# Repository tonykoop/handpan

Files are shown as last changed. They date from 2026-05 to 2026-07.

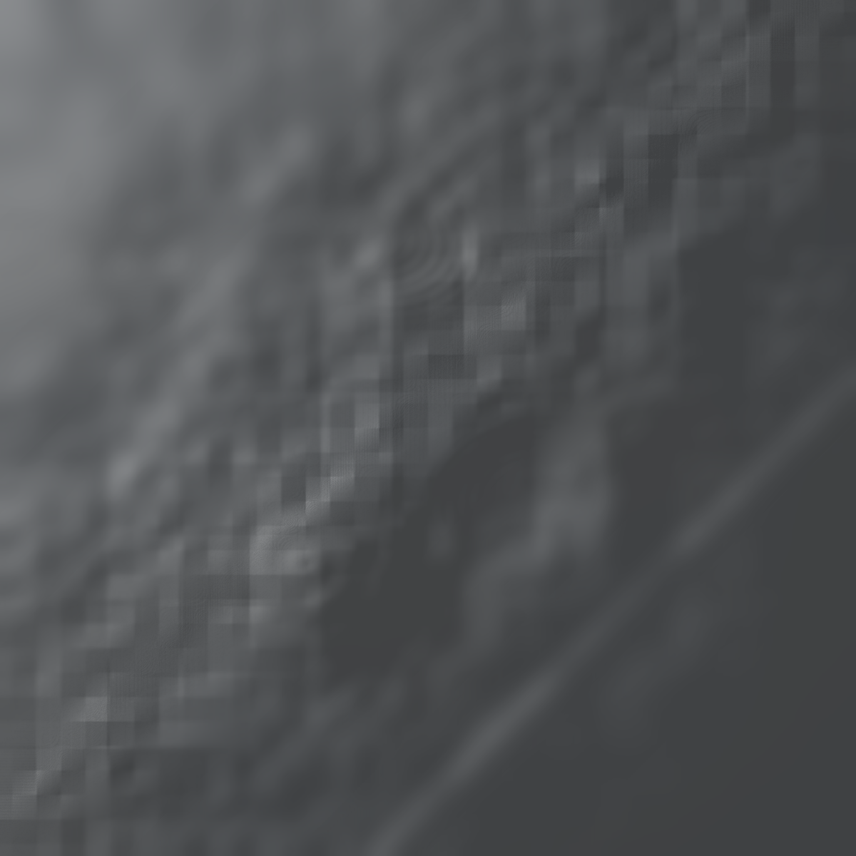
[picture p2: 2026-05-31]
images/macro/ding-and-tone-field.png

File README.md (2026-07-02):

# Handpan

Status: L2 V5 build-packet candidate; measurement-required before any L3/L4
tuning, CAD, or public-release claim.

Engineering documentation and parametric design table for a D Kurd root-mode handpan: the contemporary tuned-shell, tongueless metal hand drum built from two formed steel shells, a center Ding, eight surrounding tone fields, and a bottom Gu port.

Part of the [tonykoop/instrument-maker](https://github.com/tonykoop/instrument-maker) catalogue.

This repo is intentionally framed as a private research packet, not a promise that the spreadsheet can predict a finished handpan. Handpan tone fields are governed by hammered shell geometry, work-hardening, residual stress, shell coupling, heat/surface treatment, and tuner technique. The calculations in `handpan-design-table.xlsx`, `design.md`, and `handpan-starter.wl` are first-order sanity checks for scale, Gu behavior, and documentation. Final pitch, tuned dimple geometry, partial balance, sustain, and isolation must be earned through measured tuning passes on a real shell.

## Packet Map

- `design.md` - root-mode design intent, D Kurd note map, assumptions, and empirical tuning strategy.
- `tuning-tonality-notes.md` - Round 3 9-note D Kurd tonality notes, partial targets, and acoustic reference citations.
- `family-spec.csv` - root packet row plus variant rows that should not be released without measured prototypes.
- `bom.csv`, `sourcing.csv`, `cut-list.csv` - purchasing and fabrication surfaces with quote-sensitive fields kept explicit.
- `assembly-manual.md` - staged build method from shell inspection through settle/retune cycles.
- `validation.csv` - tuner-driven acceptance plan for cents error, partials, sustain, cross-talk, Gu coupling, and retuning drift.
- `validation-loop.csv` - Round 31 measurement loop for shell inspection, forming, heat/surface treatment, tuning, cross-talk, Gu response, and review gates.
- `measured-partial-strike-log.csv` - empty Round 35a strike/FFT/cross-talk log template; all rows remain `measurement_required` until real shell captures are recorded.
- `visual-output-register.csv` - authority map that keeps workbook/design-table inputs separate from concept-only SVG/PDF/explorer visuals.
- `cad/mcp-session-log.md` - provenance note recording that no MCP-generated V5 artifacts were produced in the Round 31 patch.
- `measurement-protocol.md` - issue #7 protocol for measured partials,
  cross-talk strike logs, microphone posture, and claim gates.
- `data/measured-partial-log.csv` - blank measurement template for field
  fundamentals and partial captures; no measured values are present yet.
- `data/cross-talk-strike-log.csv` - blank strike-log template for neighbor
  response and isolation review; no measured values are present yet.
- `qmd-step-0.md` - Round 2 retrieval record and QMD crash note.
- `validation-report.md` - current validator results and human-review gates before any public release.
- `public-release-checklist.md` - explicit path from private research packet to safe public release.
- `risks.md` - red-team review covering metal forming, heat/work-hardening, repeatability, and public-release limits.
- `drawing-brief.md`, `cad/handpan-cad-brief.md`, `cnc/fixture-cnc-brief.md`, `drawings/drawing-index.md` - CAD/CNC/drawing briefs for shells, fixtures, templates, and inspection views.
- `capstone-deck.md`, `capstone-manifest.json`, `print-packet.md`, `print-packet.html`, `site/index.html` - presentation, print, and static-site handoff artifacts.
- `cad/handpan.scad` - non-dimensional two-shell bounding envelope (top/bottom
  shell, rim joint, Ding-zone marker, Gu port); authority `pending_measurement`.
  Tone-field dimple geometry is explicitly out of scope.
- `evolution/` - evolution-pipeline Stage 0 intake: master manifest,
  design-intent, and revision register (Gate A not yet run).

## Current Root Mode

The current packet starts from the workbook defaults:

- Scale: D Kurd, 9 notes.
- Shell: 21 in nominal diameter, 9.5 in total height, 1.0 mm steel.
- Material path: nitrided DC04 preferred for first controlled build; stainless is allowed as a separate measured branch.
- Gu: 3.5 in nominal port with 0.5 in rolled lip, yielding a workbook first-order Helmholtz estimate near 115 Hz.
- Notes: D3 Ding plus A3, Bb3, C4, D4, E4, F4, G4, A4 fields.

## Round 31 V5 Issue Boundary

For the Round 31 V5 issue sweep, this repo is a private research/prototype
planning packet. It is useful for procurement, fixture planning, tuner review,
and evidence capture, but it is not L3, build-ready, measured, or publicly
release-ready evidence. The D Kurd note map and Gu estimate are documented
targets. Final pitch, dimple geometry, forming sequence, heat-treatment effects,
partial balance, sustain, cross-talk, and Gu response must be measured on a
real shell.

## Round 2 Issue #7 Measurement Surface

Issue #7 adds the missing measured-partial and cross-talk strike-log structure
before any stronger tuning claim. The note names in this repo remain target
program information only. The packet cannot claim tuned partials, field
isolation, final sustain, or public-ready musical behavior until
`data/measured-partial-log.csv` and `data/cross-talk-strike-log.csv` contain
real captures from a real shell, reviewed against `measurement-protocol.md`.

## Reality Check

The handpan should remain private until a human handpan tuner or metal-forming lead reviews the packet, approves the shell process, and signs off measured prototype data. The packet is useful for procurement, fixture planning, documentation, and validation discipline. It is not a guaranteed path to a concert instrument.

Issue #7 evidence starts in `measured-partial-strike-log.csv`. Do not promote tuning, partial-balance, sustain, or cross-talk claims from the D Kurd targets alone; each claim needs matching strike/FFT rows, audio or image evidence, and tuner review.

## Public Release Path

The repo is useful now as a private prototype handoff. Public release requires the gates in `public-release-checklist.md`: specialist review, supplier/process evidence, measured tuning data, safety review, and a public-claims pass. Until those are complete, describe the work as a research packet and fixture/documentation baseline.

## License

[CC BY 4.0](LICENSE) - see LICENSE for details.

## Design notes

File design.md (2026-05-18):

# Handpan Root-Mode Design

## Intent

Build a D Kurd handpan research packet that gives Tony's shop a practical first shell, tuning workflow, procurement list, validation plan, and documentation bundle while staying honest about the core unknown: handpan pitch is not determined by a single spreadsheet dimension. The root deliverable is a prototype-planning packet for a tuner-led build, not a guarantee of final musical quality or a measured V5 build packet.

## Design Position

- Instrument: handpan / hang-style steel idiophone.
- Mode: root-mode packet at repo root.
- Scale: D Kurd, Ding plus eight tone fields.
- Target use: first controlled prototype, tuning practice shell, documentation baseline.
- Existing source artifact: `handpan-design-table.xlsx`, sheet `Handpan`.
- Governing model: coupled curved steel plate fields plus Helmholtz Gu cavity.
- Model confidence: low for final pitch, medium for rough geometric scale and Gu sanity checks.

## Starting Inputs From Workbook

| Parameter | Value | Status |
|---|---:|---|
| Shell outside diameter | 21 in / 533 mm | workbook input |
| Total shell height | 9.5 in / 241 mm | workbook input |
| Steel thickness | 1.0 mm | workbook input |
| Gu port diameter | 3.5 in / 89 mm | workbook input |
| Gu lip / neck depth | 0.5 in / 13 mm | workbook input |
| Tuning standard | A4 = 440 Hz | workbook input |
| Number of tone fields | 9 | workbook input |
| Material | nitrided DC04 preferred | workbook input |

The workbook estimates Gu frequency from a Helmholtz expression using a lenticular volume approximation. With the current inputs, the Gu estimate is about 115 Hz, near Bb2, before real shell volume, port edge shape, and air/loading effects are measured.

## Target Scale

| Field | Note | MIDI | Fundamental Hz | Octave Hz | Compound 5th Hz | Layout | First field size estimate |
|---|---:|---:|---:|---:|---:|---|---|
| Ding | D3 | 50 | 146.83 | 293.66 | 440.00 | center | formed convex dome, tuner-defined |
| Field 1 | A3 | 57 | 220.00 | 440.00 | 660.00 | lower left | 3.50 x 4.55 in oval estimate |
| Field 2 | Bb3 | 58 | 233.08 | 466.16 | 699.23 | lower right | 3.40 x 4.42 in oval estimate |
| Field 3 | C4 | 60 | 261.63 | 523.25 | 784.88 | mid left | 3.21 x 4.17 in oval estimate |
| Field 4 | D4 | 62 | 293.66 | 587.33 | 880.00 | mid right | 3.03 x 3.94 in oval estimate |
| Field 5 | E4 | 64 | 329.63 | 659.26 | 988.88 | upper left | 2.86 x 3.72 in oval estimate |
| Field 6 | F4 | 65 | 349.23 | 698.46 | 1047.69 | upper right | 2.78 x 3.61 in oval estimate |
| Field 7 | G4 | 67 | 392.00 | 784.00 | 1176.00 | top left | 2.62 x 3.41 in oval estimate |
| Field 8 | A4 | 69 | 440.00 | 880.00 | 1320.00 | top right | 2.47 x 3.22 in oval estimate |

Field sizes are only layout starters. They should be used to make removable templates and inspection overlays, not final machining drawings.

## Acoustic Model

The first-order plate sanity check is:

```text
f1 ~= (kappa / (2 pi)) * (h / a^2) * sqrt(E / (rho * (1 - nu^2)))
```

where `h` is sheet thickness, `a` is an effective tone-field radius, and `E`, `rho`, and `nu` are steel properties. For a real handpan this equation is incomplete because hammered curvature, residual stress, work-hardening, anisotropic stiffness, dimple shape, shell boundary conditions, and coupling to other fields all shift the modes.

The Gu sanity check is:

```text
fH = (c / (2 pi)) * sqrt(A / (V * Leff))
```

where `A` is the Gu area, `V` is enclosed shell volume, and `Leff` is the port neck with end correction. The Gu should be measured after the shells are joined, because the actual cavity volume and port edge are build-specific.

## Empirical Tuning Strategy

The prototype is accepted by measurement, not prediction:

1. Form or purchase matched shells and document diameter, height, thickness map, mass, and material certificate.
2. Mark the Ding and eight fields using removable templates from the table above.
3. Rough-form the Ding and fields, leaving pitch intentionally flat enough to allow upward tuning.
4. Record baseline impulse response for every field before final tuning.
5. Tune the Ding first, then the lowest surrounding field upward through the scale.
6. For each field, tune three partial targets: fundamental, octave, and compound fifth.
7. After each field is adjusted, remeasure all previously tuned fields for drift and cross-talk.
8. Join shells only after the top shell is stable enough to survive a 24-hour rest without large drift.
9. After glue cure, tune through the Gu, then repeat rest and retune cycles until drift is acceptable.

## Acceptance Targets

- Fundamental cents error: goal within +/-8 cents after final settle, stretch target +/-5 cents.
- Octave partial: goal within +/-12 cents relative to 2x fundamental.
- Compound fifth partial: goal within +/-15 cents relative to 3x fundamental.
- Sustain: record T60 or practical decay-to-noise time per field; flag fields that choke or ring excessively.
- Cross-talk: striking any field should not pull a neighbor louder than -18 dB relative to the struck field's fundamental unless musically intentional.
- Retuning drift: after a one-week rest, each fundamental should remain within +/-10 cents of its last accepted measurement.

## Deliberate Unknowns

- Final field geometry after tuning is TBD until measured.
- Hammer recipes are TBD and must be logged by the tuner.
- Heat treatment schedule is supplier/process dependent.
- Dimple geometry, shoulder shape, and tone-field isolation are measurement-required and must not be inferred from the starter SVG layout.
- Adhesive selection needs compatibility testing with shell finish and rim geometry.
- Public release status is TBD until IP, safety, supplier, and human tuning review are complete.

## Build Classification

This is a root-mode research packet. It is suitable for a controlled first prototype, quote requests, fixture planning, shop review, and build-log setup. It is not suitable as a public "make a guaranteed handpan" recipe. See `validation-loop.csv` for the measurement gates that must close before any stronger readiness claim.

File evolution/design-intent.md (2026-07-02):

# Design Intent — handpan rev A

- Master CAD: `cad/handpan.scad` (sha256: 10a5e8d80ba57a5c706bd6ea92a2c84ce4aafa239d8eb2ffeb1638af2aa49fca) — a non-dimensional two-shell bounding envelope, driven by `handpan-design-table.xlsx` (sha256: 80c50005ce95baa1bfa12314e45540738dd1dd5cb3201e6eb3768304953d73db).
- Function: D Kurd root-mode handpan / hang-style steel idiophone. Two hammered steel shells form a Ding (center) plus eight surrounding tone fields and a bottom Gu (Helmholtz) port, coupled through the shell body (design.md Design Position, Governing Model). Tone field pitch is earned by measured tuning passes, not predicted by geometry (design.md Empirical Tuning Strategy).
- Environment: struck/hand-played idiophone; thin steel shells are forming-hazard-sensitive (risks.md Metal Forming Hazards).
- Target qty: 1 (prototype). Deadline: TBD. Budget/unit ceiling: TBD.

## Critical dimensions (carry tolerances)

| Feature | Nominal | Tolerance | Why critical | Source |
| --- | --- | --- | --- | --- |
| Shell outside diameter | 21 in / 533 mm | workbook input, not measured | overall envelope, fixture sizing | design.md Starting Inputs From Workbook, cad/handpan-cad-brief.md |
| Total shell height | 9.5 in / 241 mm | workbook input, not measured | envelope, rim-joint planning | design.md Starting Inputs From Workbook |
| Steel thickness | 1.0 mm | workbook input, not measured | pitch model input, forming risk | design.md Starting Inputs From Workbook |
| Gu port diameter / neck depth | 3.5 in / 0.5 in | workbook input, not measured | Helmholtz sanity check only | design.md Starting Inputs From Workbook |
| Tone field layout (9 fields incl. Ding) | design.md Target Scale table (layout starters only) | measurement_required — explicitly OUT OF SCOPE for cad/handpan.scad | final pitch, tuner-driven | design.md Target Scale; cad/handpan-cad-brief.md "Do not model tuned tone fields as final manufacturable pitch geometry" |

## Incidental (free for DFM)

- Shell surface finish/color; ding-zone marker diameter in cad/handpan.scad (layout reference only, not a tuned dimple spec).

## Must-nots (DFM may never violate)

- Never model tone-field dimple geometry as final manufacturable pitch geometry — cad/handpan.scad is envelope-only per cad/handpan-cad-brief.md.
- Do not treat handpan-design-table.xlsx scale values as calibrated tuned geometry (register DST-001: authority pending_measurement).
- Do not join shells before the top shell survives a 24-hour rest without large drift (design.md Empirical Tuning Strategy step 8).
- Follow risks.md Metal Forming Hazards PPE/fixture mitigations before any forming or hammering pass.

## Material intent

- Preferred: nitrided DC04 steel shells (design.md Starting Inputs From Workbook); see bom.csv/sourcing.csv for procurement detail.
- Acceptable subs: per risks.md Heat And Work-Hardening Assumptions — do not mix stainless and nitrided assumptions in one measurement set.
- Forbidden: none recorded.

## Stage status

Stage 0 intake complete 2026-07-01. Gate A (Alpha shop compile) NOT yet run — no concessions logged, nothing presented as shippable.

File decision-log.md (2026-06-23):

# Handpan Decision Log

## Decision 1 — Shell Material and Tuner Path

**Status:** Decided (planning-level; no measurement evidence yet)
**Refs:** issue #7

### Shell

| Option | Chosen? | Rationale |
|---|:--:|---|
| DC04 deep-draw steel, 2.0 mm blank | **Yes** | Widely available from Metall Pfeiffer/Havel or domestic steel service; known forming behavior; case-hardening via nitriding is available as an optional post-form step |
| Stainless 304 / 316, 1.5 mm blank | Fallback | Higher spring-back; tooling force increase; research path only |
| Nitrided / hardened pre-treated sheet | Deferred | Pre-nitrided stock is scarce; defer until DC04 path is validated |

**Chosen path:** Start with DC04 raw blank. Shell thickness target: 2.0 mm flat, ~1.2 mm measured at formed crown after hydroforming or deep press. Nitriding is an optional post-form step, not a prerequisite.

### Tuner / FFT Capture

| Option | Chosen? | Rationale |
|---|:--:|---|
| Peterson StroboPlus HD (hardware strobe) | **Yes** | Reference-grade ±0.1 cent accuracy; offline; no cloud dependency |
| Audacity FFT (software, laptop mic) | Yes (supplemental) | Free; cross-check only; mic placement and room must be logged |
| Android tuner app (GStrings, etc.) | No (initial) | Insufficient accuracy for compound-fifth partial verification |

**Chosen path:** Primary capture = Peterson StroboPlus HD + close-field mic (~5 cm, cardioid) into Audacity for FFT screenshot. Every row in `measured-partial-strike-log.csv` must name the tuner model, gain setting, room noise level, and audio file or FFT screenshot path.

### Public / Private Handling for Evidence

| Artifact | Public? | Rationale |
|---|:--:|---|
| Protocol template (`measurement-protocol.md`) | Public | Process definition only; no shell-specific data |
| Log template (`measured-partial-strike-log.csv`, `data/measured-partial-log.csv`) | Public | Template rows marked `measurement_required`; no real values |
| Populated log rows (real Hz readings, FFT screenshots) | **Private until reviewed** | Measurement evidence is retained locally in `data/`; only a reviewed summary is committed to main |
| Audio captures (`.wav`, `.flac`) | Private / local only | Large files; store locally or in private object storage; never commit to GitHub |

**Decision:** Only template rows and protocol docs are committed public. Populated measurement rows go into `data/` (already listed in `.gitignore` drafts) until a tuning lead or fabrication reviewer signs off. After review, a sanitized summary row is promoted to `measured-partial-strike-log.csv` with a reference to the private evidence file path.

## Packet Readiness Gate

The packet stays at **L2 planning** (templates defined, protocol decided, no real shell evidence) until at least:

- [ ] One physical shell blank acquired and logged in `validation-loop.csv` vl001
- [ ] Material/process path documented with supplier cert or process note (vl002)
- [ ] Template layout photographed and reviewed (vl003)
- [ ] Ding fundamental and octave partial captured and within ±5 cents of target (vl004)

Advancing to L3 requires real measured rows, not template rows.

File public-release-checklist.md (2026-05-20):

# Public Release Checklist

This repo can be useful before it is publicly releasable. Treat the current packet as a private research and shop-review bundle until every gate below is complete.

## Current Use

Allowed now:

- Quote shells, tooling, measurement equipment, fixtures, adhesive coupons, and finishing supplies.
- Review the D Kurd layout, Gu target, and validation method.
- Build non-acoustic fixtures: tuning support ring, removable templates, inspection overlays, and photo/documentation setup.
- Run scrap-shell or coupon trials for hammers, edge finishing, adhesive, and finish compatibility.

Not allowed to claim yet:

- Final tone-field contours.
- A proven hammer recipe or tuning sequence.
- Concert-quality pitch accuracy, sustain, or cross-talk isolation.
- Validated nitriding, heat-treatment, stainless, or supplier process behavior.
- A general public recipe for building a finished handpan.

## Specialist Gates

| Gate | Required reviewer | Evidence to add |
|---|---|---|
| Shell process | Experienced handpan maker or metal-forming lead | Supplier shell data, material certificate, forming notes, thickness map, mass, hardness/process notes if available |
| Tone-field forming | Experienced handpan tuner | Signed review of layout, hammer plan, stop conditions, and tuning-log fields |
| Heat / surface process | Heat-treatment or supplier reviewer | Nitriding/stainless branch decision, process temperature notes, distortion risk, compatibility with finish and adhesive |
| Safety | Shop lead | PPE plan, hearing protection plan, Gu/rim deburr inspection, fixture stability, fire/fume plan if heat is used |
| Public release | Tony plus IP/public-safety reviewer | Confirmation that photos, supplier details, methods, claims, and terminology are safe to publish |

## Measurement Gates

Populate `validation.csv` before public release:

- Incoming shell diameter, height, thickness map, mass, material path, and Gu geometry.
- Gu response after assembly or controlled cavity test.
- Ding plus eight field fundamentals, backed by `measured-partial-strike-log.csv`.
- Octave and compound fifth partials for every field, backed by FFT/strobe rows in `measured-partial-strike-log.csv`.
- Strike matrix for cross-talk, with struck-field and neighbor-field rows in `measured-partial-strike-log.csv`.
- Sustain or practical decay for every field, linked to the same strike-log evidence.
- Post-assembly drift after at least one week.
- Final Gu/rim tactile safety inspection.

## Drawing Gates

The current drawings are layout and inspection drawings. Before public release, add or revise:

- General assembly view from actual shell measurements.
- Bottom Gu drawing from the final cut port and edge treatment.
- Measurement overlay for shell-thickness points, strike locations, and microphone reference.
- Template sheet labeled `layout estimate`, not `final tone geometry`.
- Photos or screenshots showing the real prototype, not only schematic layouts.

## Release Decision

The issue can be considered complete for a private build packet when the repo validates cleanly and clearly escalates the human-only work.

The repo should not be called public-ready until the specialist and measurement gates above are complete.

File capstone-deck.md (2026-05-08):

# Title

D Kurd Handpan Root-Mode Prototype

# Project Intent

Create a research-grade root packet for a D Kurd handpan that is useful in the shop and honest about uncertainty. The packet supports shell procurement, fixture planning, layout, empirical tuning, validation, and private review before any public release.

# Instrument Context

The handpan is a coupled steel-shell idiophone with a center Ding, surrounding tuned fields, and a bottom Gu port. Its musical behavior comes from shaped steel, residual stress, tuned partials, and shell coupling.

# Source Artifacts

The starting design comes from `handpan-design-table.xlsx`, sheet `Handpan`, with a 21 in shell, 1.0 mm steel, 3.5 in Gu, A=440, and a D Kurd 9-note layout.

# Physics Model

The packet uses plate and Helmholtz formulas as first-order sanity checks only. Final pitch is determined by measured hammered geometry, work-hardening, boundary conditions, field coupling, and tuner decisions.

# Scale And Layout

The target root mode is D Kurd: D3 Ding with A3, Bb3, C4, D4, E4, F4, G4, and A4 surrounding fields. The oval field sizes are removable-template starters, not final acoustic contours.

# Manufacturing Strategy

The first build should use purchased or professionally formed shells. CNC and CAD are used for support rings, templates, drawings, and inspection aids rather than final tuned tone-field geometry.

# Tuning Workflow

Tune the Ding first, then move from low fields to high fields. Each field is measured for fundamental, octave, and compound fifth, and each change triggers a recheck of previously tuned fields.

# Validation Plan

Acceptance is tuner-driven: cents error, overtone behavior, sustain, cross-talk, Gu response, and retuning drift are logged across rough tuning, shell closure, final tuning, and one-week rest cycles.

# Risks

Major risks include metal-forming hazards, heat-treatment distortion, tuning repeatability, false precision in formulas, adhesive/rim effects, and premature public release. These are documented in `risks.md`.

# Private Review Gate

The handpan should stay private until a human tuner and metal-forming reviewer approve the process and measured data. The packet is a disciplined prototype handoff, not a finished-instrument guarantee.

# Deliverables

The repo now includes design, BOM, sourcing, cut list, validation, assembly, RFQ, drawing/CAD/CNC briefs, visual BOM brief, Wolfram starter, risks, photo shotlist, print packet, site, and capstone manifest artifacts.

# Next Actions

Source or inspect a practice shell, verify supplier data, build the tuning frame and templates, run coupon tests, and begin a measured tuning log before committing the final shell pair.

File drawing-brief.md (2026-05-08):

# Drawing Brief

## Purpose

Create drawings that help a fabricator, tuner, and reviewer inspect the handpan prototype. These drawings should not imply that the tone fields can be machined to final pitch. They are layout, fixture, inspection, and communication drawings.

## Required Drawing Set

1. General assembly side view: two-shell lenticular body, 21 in nominal diameter, 9.5 in total height, rim joint, bottom Gu location.
2. Top layout view: Ding and eight field clock positions, note names, target fundamentals, and estimated oval layout envelopes.
3. Bottom view: Gu center, 3.5 in nominal port, lip/edge finish note.
4. Section view: shell thickness, rim bond region, Gu lip, and approximate internal volume region.
5. Fixture view: tuning support ring contact surface and shell support datum.
6. Template sheet: Ding and eight removable layout templates.
7. Validation overlay: measurement point map for thickness, strike positions, and microphone reference.

## Drawing Rules

- Mark all tone-field final shapes as `tuner adjusted`.
- Mark field dimensions as `layout estimates`.
- Include both inch and metric dimensions.
- Include datum references: shell center, 12 o'clock reference, rim plane, Gu center.
- Avoid CNC-style final contour dimensions for tuned areas.
- Add notes for inspection and measurement logging.

## CAD/CNC Deliverables

- `cad/handpan-cad-brief.md` for model setup.
- `cnc/fixture-cnc-brief.md` for support ring and templates.
- `drawings/drawing-index.md` for drawing list and review gates.

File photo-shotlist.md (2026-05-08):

# Photo Shotlist

## Incoming Materials

- Shell pair top, side, inside, rim, and bottom views.
- Closeups of material markings, supplier labels, and surface finish.
- Thickness measurement setup and measurement grid.
- Gu port before and after deburring.

## Layout And Forming

- Centerline and clock reference on top shell.
- Ding template aligned to shell center.
- Each tone-field template in place with note label visible.
- Tuning frame/support ring before shell is placed.
- Dimple tooling and hammer set with scale reference.

## Tuning Documentation

- Microphone/tuner setup showing fixed distance.
- FFT/spectrum screen for each field's three partials.
- Tuning log page after one complete pass.
- Cross-talk measurement setup.
- Rest/retune comparison table.

## Assembly

- Dry-fit rim alignment marks.
- Adhesive coupon test.
- Adhesive bead before shell closure.
- Clamping setup during cure.
- Gu access during final tuning.

## Finish And Final Review

- Finished Gu edge.
- Surface protection application.
- Final assembled top, side, and bottom views.
- Case/storage setup.
- Human tuner review session or marked measurement signoff.

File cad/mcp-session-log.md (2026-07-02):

# MCP Session Log

No MCP-generated V5 artifacts were produced for this Round 31 patch.

The current handpan packet contains text-authored docs, CSVs, workbook-derived
planning values, starter SVG drawings, and an existing studio explorer. These
are useful for review and prototype planning, but they are not evidence of a
measured handpan, calibrated tuned dimple geometry, verified forming process,
heat-treatment recipe, or final shop-ready tone-field layout.

| timestamp_utc | tool | artifact | session_id | parent_artifact | role | authority | notes |
| --- | --- | --- | --- | --- | --- | --- | --- |
| 2026-05-18 | none | visual-output-register.csv | none | handpan-design-table.xlsx | authority register | metadata | Records workbook/design-table authority and concept-only visual previews. |
| 2026-05-18 | none | validation-loop.csv | none | validation.csv | validation loop | measurement plan | Adds measurement-required gates for shell inspection, forming, tuning, Gu response, cross-talk, and human review. |
| 2026-05-29 | none | visual-output-register.csv rows SVG-003, DXF-001 | none | DST-001 | dimple layout pre-registration | pending | Registered planned Illustrator MCP dimple-layout vector artifacts (issue #4). Session not yet run; authority=pending. Files do not yet exist. Upgrade authority to fabrication after running MCP session and validating DXF dimensions against design-table. |
| 2026-05-29 | none | validation.csv rows VAL-023, VAL-024, VAL-025 | none | measured-partial-strike-log.csv | validation gates | measurement plan | Added strike-log completeness gate (VAL-023), cross-talk matrix completeness gate (VAL-024), and dimple layout fabrication pre-gate (VAL-025) — issue #7 and #4 protocol structure. |
| 2026-07-01 | claude-code (Fable 5) | bom.csv, sourcing.csv, cut-list.csv, validation.csv, handpan-design-table.xlsx, family-spec.csv | fable-v5-refresh-2026-07-01 | handpan-design-table.xlsx | packet_refresh | fabrication | V5 refresh pass: reviewed tabular packet data against design-table baseline; no dimension changes made. Row added to satisfy V5 fabrication-artifact logging requirement. |
| 2026-07-01 | claude-code (Fable 5) + OpenSCAD CLI | cad/handpan.scad | fable-v5-refresh-2026-07-01 | handpan-design-table.xlsx, design.md, cad/handpan-cad-brief.md | cad_authoring | pending_measurement | Non-dimensional two-shell bounding envelope (top/bottom shell, rim joint, Ding-zone marker, Gu port) authored from workbook-input scale dimensions (shell_diameter_in=21, shell_height_in=9.5, steel_thickness_mm=1.0, gu_diameter_in=3.5). Tone-field dimple geometry explicitly out of scope per cad/handpan-cad-brief.md ("Do not model tuned tone fields as final manufacturable pitch geometry"). OpenSCAD render check: pass (openscad -o STL, exit 0). |

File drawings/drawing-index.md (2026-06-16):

# Drawing Index

## Planned Drawings

| Drawing | Purpose | Status |
|---|---|---|
| HPAN-001 Top Layout | Ding and eight field clock positions with target notes | `01-top-layout.svg` |
| HPAN-002 Section / Fixture | Shell side profile, rim joint, Gu port, total height, tuning support ring | `02-gu-section-fixture.svg` |
| HPAN-003 General Assembly | Overall 21 in shell pair, rim, Gu, top/bottom orientation | brief ready |
| HPAN-004 Bottom Gu | Gu port diameter, edge/lip note, safety finish | brief ready |
| HPAN-005 Tuning Frame | Support ring geometry and contact notes | covered in HPAN-002 starter |
| HPAN-006 Template Sheet | Ding and tone-field layout templates | brief ready |
| HPAN-007 Validation Map | Strike points, mic placement, thickness map locations | brief ready |
| HPAN-008 Issue #4 Dimple Layout Vector Test | Illustrator-MCP register row and pending-authority brief for a future vector test | `issue-4-dimple-layout-vector-test.md` |

## Drawing Warning

All tone-field contours are layout estimates. Final shape and pitch are tuner-adjusted after measured hammering passes.

The starter SVGs are intentionally conservative review drawings. They are suitable for layout discussion, fixture planning, and shop review; they are not final manufacturable tone-field geometry.

Issue #4 does not add a new vector drawing. Its brief records the gates a future
Illustrator-MCP dimple-layout test must satisfy before any vector output can be
treated as more than `pending_measurement`.

## Public-Release Drawing Gates

Before public release, replace or supplement the starter drawings with actual shell measurements and build evidence:

- actual shell profile, rim condition, and Gu edge detail
- measurement overlay for shell thickness, strike points, and microphone placement
- template sheet labeled as `layout estimate`
- photo references for the real shell and fixtures
- reviewer signoff that no drawing implies CNC-machined final pitch geometry

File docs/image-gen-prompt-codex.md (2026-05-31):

# Image-Gen Prompts

Concept image only; not fabrication authority. Do not include cut-ready dimensions, tone-field templates, dimple geometry, tuning values, shell process parameters, or toolpaths.

## Hero Prompt

Photorealistic 3/4 product photograph of a finished D Kurd research handpan: two joined nitrided steel shells forming a smooth lenticular hand drum, a central Ding dome surrounded by eight tuned oval tone fields, subtle hammered and heat-treated surface texture, a rolled rim seam, bottom Gu port hinted by the side shadow, dark blue-gray satin steel with gentle iridescence, realistic lap-playable scale cues, clean neutral studio background, soft directional studio lighting, ~50mm lens, high detail, no logos.

## In-Context Prompt

Photorealistic workshop tuning scene of the handpan on a padded stand, natural light over the nitrided shell, a tuner gently strikes a tone field while removable paper templates, small hammers, and a measurement microphone sit nearby, the Ding and surrounding D Kurd fields visible as formed surfaces rather than cut tongues, quiet private research atmosphere, realistic hands, shallow depth of field, concept visualization only.

## Detail Prompt

Photorealistic macro close-up of the signature handpan tone-field surface: one oval formed field with a central dimple and shoulder transition in dark nitrided steel, fine hammer marks, subtle heat-treatment color, neighboring fields and the Ding softly blurred, a fingertip or soft mallet just out of contact, soft raking light emphasizing curvature, high detail, no pitch labels or dimension overlays.

## Negative / Avoid

No text, logos, watermarks, slit tongues, ceramic surface, dimension callouts, fake brand emblems, impossible perfectly flat tone fields, extra fingers, or decorative patterns unrelated to the D Kurd handpan layout.

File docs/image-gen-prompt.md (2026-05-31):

# Image-Gen Prompts

Concept image only; not fabrication authority. Do not include cut-ready dimensions, hole locations, tone-field geometry, dimple shapes, or toolpaths. Tone-field shapes are tuner-adjusted and must never be drawn as final.

## Hero Prompt

Photorealistic 3/4 product photograph of a finished D Kurd handpan: a smooth lenticular UFO-shaped steel hand drum formed from two domed sheet-steel shells joined at a clean rim seam, a single convex central Ding dome at the top center surrounded by a ring of eight gently hammered oval tone fields, each tone field a softly dimpled depression with a subtle raised note interface, the whole satin-grey nitrided steel surface showing faint hammer-worked texture and a warm dark patina, hand-playable lap-scale cues, brushed metal catching soft directional studio light, clean neutral studio background, soft directional studio light, 3/4 angle, ~50mm lens, high detail, photorealistic, no text labels.

## In-Context Prompt

Photorealistic image of the D Kurd handpan staged on a player's lap in a quiet instrument-maker's workshop, the musician's hands resting lightly over the central Ding and an adjacent tone field as if about to strike, the lenticular steel body angled so the ring of eight oval tone fields around the Ding is visible, a tuning frame support ring and a small set of tuning hammers resting on the bench nearby for storytelling, warm natural window light, satin nitrided steel surface with faint hammer texture, shallow depth of field, environmental storytelling, concept visualization only.

## Detail Prompt

Photorealistic macro close-up of the signature mechanism: the central convex Ding dome and two neighboring hammered oval tone fields on the steel handpan top shell, each tone field a smooth shallow dimpled depression worked into the curved steel with soft shoulder transitions and subtle concentric hammer-forming marks, satin nitrided grey-steel surface with faint patina, raking light revealing the gentle curvature and worked texture of the shell, the rim seam blurred at the frame edge, high detail, no measurements.

## Negative / Avoid

No text, logos, watermarks, or fake maker marks; no dimension callouts; no cut tongues, slots, or machined tone-field contours (tongueless tuned-shell drum, tuner-adjusted fields); anatomically plausible hands if a player is shown.

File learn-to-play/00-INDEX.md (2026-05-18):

# Handpan — Starter Songbook

Your handpan is tuned to **D Kurd** (D natural minor / Aeolian):

```
Ding: D3 (center, lower dome)
Tone fields (arranged in a circle on the upper dome):
  A3 — Bb3 — C4 — D4 — E4 — F4 — G4 — A4
```

The handpan is played with bare hands — thumbs, fingertips, and the heel of the hand.
Never use mallets, picks, or hard objects on the handpan.

## Difficulty key
- ★☆☆ — Beginner: ding + adjacent fields, slow patterns
- ★★☆ — Intermediate: full field circle, simple melodies
- ★★★ — Advanced: bass tones, taks, cross-handed patterns

## Stroke vocabulary
| Stroke | Hand | Sound |
|---|---|---|
| **Ding** | Thumb or ring finger on ding dome | Deep, resonant center tone |
| **Tone** | Fingertip on outer edge of tone field | Clear, singing pitch |
| **Slap** | Flat finger, quick release | Short, muted "tak" click |
| **Bass** | Hand presses center of tone field then lifts | Muffled, bass-register version of field |

## Tunes in this songbook
1. `tunes/ding-meditation/` ★☆☆ — Ding exploration and drone patterns
2. `tunes/sakura/` ★★☆ — Sakura Sakura, Japanese trad. (A Bb D E)
3. `tunes/greensleeves-kurd/` ★★☆ — Greensleeves adapted for D Kurd
4. `tunes/kurd-dawn/` ★★★ — Kurd Dawn (original, D Aeolian)
5. `tunes/water-is-wide/` ★★★ — The Water Is Wide (D natural minor)

## Safety note
The handpan surface is finished steel. Keep fingernails trimmed. Do not use rings
or jewelry while playing. After playing, wipe the surface with a dry cloth and
apply a small amount of protective oil (phoenix oil or similar) monthly.

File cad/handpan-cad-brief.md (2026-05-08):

# CAD Brief - Handpan Prototype

## Scope

Model the handpan as an inspection and communication assembly: top shell, bottom shell, rim joint, Gu port, Ding zone, and eight layout zones. Do not model tuned tone fields as final manufacturable pitch geometry.

## Model Requirements

- Units: inches primary, metric secondary.
- Global variables: shell_diameter_in = 21, shell_height_in = 9.5, steel_thickness_mm = 1.0, gu_diameter_in = 3.5.
- Datums: rim plane, shell center axis, 12 o'clock clock reference, Gu center.
- Configurations: top shell layout, bottom shell Gu, assembled shell, exploded review view.
- Tone fields: surface decals/sketch envelopes only, named by note and target frequency.
- Properties table: material path, source shell, measured thickness map reference, mass.

## Review Notes

CAD is not the acoustic authority for final handpan pitch. Its job is to keep the shop aligned on shell geometry, tooling interfaces, templates, and validation points.

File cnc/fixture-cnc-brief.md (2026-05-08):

# CNC Brief - Fixtures And Templates

## Parts

1. Tuning support ring for 21 in shell.
2. Removable Ding template.
3. Eight oval tone-field layout templates.
4. Measurement overlay with strike and microphone reference marks.

## Materials

- Support ring: steel, plywood, or MDF prototype; final frame should be stiff and padded.
- Templates: acrylic, hardboard, plywood, or printed film.

## Constraints

- CNC parts support layout and measurement only.
- Do not cut, stamp, or machine final tone fields based solely on the CSV dimensions.
- Edges contacting the shell must be padded or polished.
- Mark all templates with note name, target Hz, and `layout estimate`.

## Output Files To Generate Later

- DXF/SVG support ring profile.
- DXF/SVG template sheet.
- PDF inspection overlay.

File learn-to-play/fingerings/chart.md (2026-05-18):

# Handpan Field Layout Reference (D Kurd)

```
         ┌──────────────────────────────┐
         │         TOP VIEW             │
         │                              │
         │       A4 ●     ● G4         │  ← 6 o'clock / 12 o'clock positions
         │                              │
         │   F4 ●             ● E4     │  ← 4:30 / 7:30 positions
         │                              │
         │       D4 ●     ● C4         │  ← 3 o'clock / 9 o'clock positions
         │                              │
         │   Bb3●              ● A3    │  ← 1:30 / 10:30 positions
         │                              │
         │         ╭─────────╮          │
         │         │ DING    │          │  ← Center dome (D3)
         │         │  D3     │          │
         │         ╰─────────╯          │
         └──────────────────────────────┘

Note: Actual clock positions vary by builder. This is a representative D Kurd layout.
Learn your specific instrument's field positions by touch before reading notation.
```

## Stroke techniques
| Stroke | Finger | Sound |
|---|---|---|
| Ding | Thumb or ring fingertip | Deep, resonant, long sustain |
| Tone | Fingertip (index or middle) at field center | Clear singing tone |
| Tak/slap | Flat of finger, quick release | Short percussive click |
| Bass slap | Whole hand, muffle after strike | Low, muted field tone |

## Field-to-note map (D Kurd, clockwise from lower left)
A3 → Bb3 → C4 → D4 → E4 → F4 → G4 → A4 (→ back to A3)

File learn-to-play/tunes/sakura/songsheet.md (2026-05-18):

# Sakura Sakura — Songsheet (Handpan)

**Key:** A Bb D E (Sakura/In pentatonic)  **Tempo:** ♩= 66
**Meter:** 4/4  **Difficulty:** ★★☆  **Range:** A3–E4
**Source:** Traditional Japanese, Edo period, public domain

## Music
```
X:2 T:Sakura Sakura M:4/4 L:1/4 Q:1/4=66 K:Dmin
A B d2 | A B d2 | A B d e | d B A2 |
A B d e | d B A2 | A d d B | A4 |
```

## Handpan fingering notes
- **A3** (A): left or right index finger on the A3 field (first field from ding)
- **Bb3** (B): adjacent field
- **D4** (d): opposite side of the field circle
- **E4** (e): next field clockwise from D4
- Return to **A4** for the final held note (or use A3 + ding together)

## Notes
- At ♩= 66, this melody should feel like a slow koto improvisation.
- The Bb (b in K:Dmin) creates the distinctive Sakura/In scale tension.
- Let each note fully bloom before the next — the handpan sustain is your friend.

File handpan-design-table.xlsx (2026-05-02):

Handpan / Hang Drum — Clamped Steel Plate + Helmholtz Resonator
Steel Idiophone · Nitrided or Stainless Steel · Ding + 8 Tone Fields · Gu Port (Helmholtz Bass) · Hand-Tuned Harmonics
DESIGN INPUTS
Shell Diameter (in) | 21.0 | ← 53 cm standard; original Hang = 52 cm (20.5"); range 18–24"
Shell Height (in) | 9.5 | ← 8–10" typical; deeper = more bass resonance
Steel Thickness (mm) | 1.0 | ← 0.8–1.2 mm; thinner = easier to shape, higher pitch tendency
Gu Port Diameter (in) | 3.5 | ← 3–4.5"; larger = lower Helmholtz bass
Gu Port Depth (in) | 0.5 | ← Rolled lip depth (neck length for Helmholtz calc)
Material | Nitrided DC04 | ← DC04 (nitrided) | 430 Stainless | Ember Steel
Tuning Standard (Hz) | 440 | ← 440 Hz standard; some makers use 432 Hz
Number of Tone Fields | 9 | ← Ding (center) + 8 surrounding; range 7–17
Selected Scale | D Kurd | ← Choose from Scale Library below (row 30+)
GU BASS — Helmholtz Resonator: f = (c/2π)√(A / (V × L))
Speed of Sound (in/s) |  | ← At 68°F / 20°C
Gu Port Area (in²) |  | ← A = π × (port_Ø/2)²
Shell Internal Volume (in³) |  | ← V ≈ ⁴⁄₃πr²h (lenticular shell: 2 oblate spheroid halves)
Gu Neck Length (in) |  | ← Physical depth + end correction (0.6 × radius)
Helmholtz Frequency (Hz)
Nearest Note |  | ← Typical handpan Gu bass range: C2–G2
Cents Deviation |  | ← + sharp / − flat from nearest ET note
SCALE LIBRARY — Popular Handpan Tunings (Ding + 8 Tone Fields)
Scale Name | Mood | Ding | 1 | 2 | 3 | 4 | 5 | 6 | 7 | 8
D Kurd | Versatile minor | D3 | A3 | Bb3 | C4 | D4 | E4 | F4 | G4 | A4
D Celtic Minor | Open, spacious | D3 | A3 | C4 | D4 | E4 | F4 | G4 | A4 | C5
C# Pygmy | Dreamy, grounding | C#3 | G#3 | B3 | C#4 | D#4 | G#4 | B4 | C#5 | D#5
E Hijaz | Exotic, Middle Eastern | E3 | B3 | C4 | D#4 | E4 | F4 | G#4 | A4 | B4
D Equinox | Meditative, floating | D3 | A3 | C4 | D4 | E4 | G4 | A4 | C5 | D5
F Sabye | Happy, uplifting | F3 | C4 | D4 | F4 | G4 | A4 | C5 | D5 | F5
E Akebono | Zen, contemplative | E3 | B3 | C4 | E4 | F4 | B4 | C5 | E5 | F5
D Aeolian | Full natural minor | D3 | A3 | Bb3 | C4 | D4 | E4 | F4 | G4 | A4
← Copy your chosen scale’s notes to the Tone Field Calculator below
TONE FIELD CALCULATOR — 9-Note Layout (Ding + 8 Fields)
Field | Note Name | MIDI # | Fundamental (Hz) | Octave (Hz) | Compound 5th (Hz) | Position | Clock Pos | Est. Field Width (in) | Est. Field Height (in) | Status
Ding (center) | D3 | 50 |  |  |  | Center | — | — | — | Dome (convex)
Field 1 (lowest) | A3 | 57 |  |  |  | Bottom-Left | 7:00:00 |  |  | Dimple (concave)
Field 2 | Bb3 | 58 |  |  |  | Bottom-Right | 5:00:00 |  |  | Dimple (concave)
Field 3 | C4 | 60 |  |  |  | Mid-Left | 9:00:00 |  |  | Dimple (concave)
Field 4 | D4 | 62 |  |  |  | Mid-Right | 3:00:00 |  |  | Dimple (concave)
Field 5 | E4 | 64 |  |  |  | Upper-Left | 10:00:00 |  |  | Dimple (concave)
Field 6 | F4 | 65 |  |  |  | Upper-Right | 2:00:00 |  |  | Dimple (concave)
Field 7 | G4 | 67 |  |  |  | Top-Left | 11:00:00 |  |  | Dimple (concave)
Field 8 (highest) | A4 | 69 |  |  |  | Top-Right | 1:00:00 |  |  | Dimple (concave)
SHELL FORMING METHODS
Method | Description | Equipment | Pros | Cons | Feasibility
Hand Sinking | Hammer flat disc into concave form over sandbag/tire | Ball peen hammer, sandbag, pneumatic hammer | Lowest cost; most traditional | Very slow; inconsistent thickness | ✅ Home shop
Spinning | Clamp disc on lathe, press forming tool as disc spins | Metal lathe 22"+ swing, buck tool | More uniform; repeatable | Needs large lathe | ⚠️ Lathe too small
Deep Drawing | Hydraulic press pushes disc through die in one stroke | Hydraulic press + die, OR buy pre-drawn shells | Most consistent; buy shells $150-300/pair | Die set expensive | ✅ Buy shells (recommended)
Hydroforming | Water pressure pushes disc through mold | Hydroform press, mold | Excellent uniformity | Industrial only | ❌ Not feasible
STEEL & NITRIDING
Raw Material | DC04 low-carbon steel (most common) or 430/301 stainless steel
Sheet Thickness | 0.8-1.2 mm (1.0 mm standard)
Flat Disc Diameter | ~24 in (shell diam x 1.15 for draw overshoot)
Gas Nitriding | 500-550C in nitrogen atmosphere; hardens surface, ceramic tap tone | Outsource to nitriding facility
Nitriding Effect | Vickers ~1000 HV; tuning stability; darker color; rust resistance
BILL OF MATERIALS
# | Item | Qty | Spec / Dimensions | Supplier / Notes | Est. Cost
1 | Pre-drawn steel shells (pair) | 1 | 53cm / 21 in diam, 1.0mm DC04 or stainless | Ayasa Instruments, Shellopan, or similar supplier | $150-300
2 | Gas nitriding service | 1 | 500-550C nitrogen heat treatment (both shells) | Local nitriding facility; skip if using stainless | $50-150
3 | Tuning ring / clamping frame | 1 | Steel ring to hold shell during tuning | CNC cut from 1/4 in steel plate, or weld from flat bar | $30-80
4 | Tuning hammers (set) | 1 | Small cross-peen, ball peen, rubber mallet | Modified jeweler's hammers; 4-8 oz heads | $40-80
5 | Dimple press / ball form | 1 | Hardened steel ball + receiver die for dimple pressing | Can use arbor press with ball bearing; or hammer by hand | $20-50
6 | Chromatic tuner + spectrum analyzer | 1 | Peterson StroboClip or software (SpectraPLUS, Audacity FFT) | Need to see fundamental + overtones separately | $30-100
7 | Shell adhesive (epoxy) | 1 | High-strength, flexible epoxy (3M DP420 or similar) | Must remain slightly flexible; rigid epoxy cracks | $20-40
8 | Gu port ring (rubber) | 1 | 3.5 in ID rubber O-ring or silicone edge trim | Protects Gu edge; improves Helmholtz tone | $5-15
9 | Protective oil / sealant | 1 | Phoenix Oil, Frog Lube, or food-grade mineral oil | Apply after each playing session (nitrided only) | $10-20
10 | Padded case / bag | 1 | 22 in soft case or hard shell case | Essential for transport and storage | $40-100
 | ESTIMATED TOTAL |  |  |  | $395-935
BUILD METHOD
# | Phase | Operation | Tools | Key Parameters | Done?
1 | Shell Prep | Acquire or form two hemisphere shells | Supplier / hydraulic press | Match top + bottom shells; verify diameter and depth
2 | Shell Prep | Cut Gu port hole in bottom shell | Hole saw, deburr tool | 3.5 in diameter; center carefully; roll edge inward
3 | Nitriding | Send both shells to nitriding facility | Outsource | 500-550C gas nitriding; skip if stainless steel
4 | Layout | Mark Ding center and 8 tone field positions on top shell | Template, marker, compass | Zigzag L-R layout ascending; use clock positions from table above
5 | Layout | Mark tone field oval boundaries with templates | Oval templates (laser-cut acrylic) | Use estimated field sizes from calculator; larger fields at bottom
6 | Forming | Press or hammer dimples into each tone field center | Dimple press / ball form / hammer | Concave dimples for fields; convex dome for Ding
7 | Pre-Stress | Pre-stress tone fields by hammering around perimeters | Cross-peen hammer | Compress metal around each note to isolate vibrations
8 | Heat Treat | Heat shell with torch to relieve forming stresses | Propane/MAP torch | Heat until blue-purple (300-350C); let cool naturally
9 | Tuning | Tune Ding fundamental first | Tuning hammer, chromatic tuner | Center of Ding raises pitch; surrounding area lowers it
10 | Tuning | Tune each tone field fundamental (1 of 3 per field) | Tuning hammer, spectrum analyzer | Work from lowest (Field 1) to highest (Field 8)
11 | Tuning | Tune octave harmonic on each field (2 of 3) | Tuning hammer, FFT analyzer | Shape the field into two perpendicular axes (Pringle shape)
12 | Tuning | Tune compound 5th harmonic on each field (3 of 3) | Tuning hammer, FFT analyzer | Verify all 3 partials in tune; check isolation from neighbors
13 | Assembly | Glue top and bottom shells together | Flexible epoxy, clamps, alignment jig | Apply even bead around rim; clamp firmly; cure 24+ hours
14 | Fine Tune | Let settle 1-2 weeks, then re-tune through Gu port | Tuning hammer (reach through Gu) | Steel has memory; re-check all 27 partials (9 fields x 3)
15 | Fine Tune | Repeat settle + retune cycle 2-3 more times | Same | Each cycle: wait 1-2 weeks, retune. Tuning becomes more stable
16 | Finishing | Clean, polish, apply protective oil; install Gu ring | Microfiber cloth, oil, rubber ring | Remove glue residue; oil nitrided surface; trim Gu edge
DESIGN NOTES
1. TUNING IS THE HARDEST PART. Expect months of practice before producing a playable instrument. Start with a practice shell.
2. Each tone field has 3 tuned partials: fundamental, octave (+12 semitones), compound 5th (+19 semitones). All 3 must be in tune.
3. Tone field shape: think two Pringles stacked perpendicular. The two axes of the oval each vibrate at different frequencies.
4. Center of field raises pitch; hammering edges lowers pitch. Work incrementally — over-hammering is very hard to undo.
5. Wave interference: certain frequencies resonate with the shell cavity and create buzzing. The Helmholtz Gu frequency is key — avoid tuning any field to that frequency.
6. Pre-drawn shells from Ayasa or similar are STRONGLY recommended for first build. Hand-sinking requires enormous practice.
7. Nitriding is optional if using stainless steel. Stainless has longer sustain, warmer tone, no rust; nitrided has crisper attack, ceramic tap.
8. The Gu port size controls the Helmholtz bass note. Larger port = higher bass; smaller = lower. Use the calculator above to estimate.
9. Typical handpan costs $1,500-$3,500 retail. Building your own for $400-900 in materials is a massive savings — but the skill investment is significant.
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

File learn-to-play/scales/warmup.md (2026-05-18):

# Handpan Warm-Up: D Kurd Field Walk

Begin each session with this ding-and-field exploration. No rhythm required.

## Ding breathing exercise
Strike the ding lightly with your left thumb. Listen to the full decay (5–8 seconds).
Breathe in as you strike; breathe out as it fades. Repeat 4 times.

## Field walk (ascending)
```
Ding (D3) → A3 → Bb3 → C4 → D4 → E4 → F4 → G4 → A4
```
Strike each with a light fingertip tone stroke. Pause 2 seconds between notes.
Listen for the resonance of each field before moving to the next.

## Interval pairs (ding + each field)
```
D3+A3  D3+Bb3  D3+C4  D3+D4  D3+E4  D3+F4  D3+G4  D3+A4
```
Each pair creates a different harmonic interval. Listen for consonance vs. tension.

## Pentatonic core (D F G A C)
```
D3 — F4 — G4 — A4 — C4 — D4 (loop)
```
These 5 notes form the pentatonic subset of D Kurd — the most harmonious nucleus.

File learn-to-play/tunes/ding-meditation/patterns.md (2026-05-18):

# Ding Meditation ★☆☆

Free-time, no rhythm. This is a listening exercise, not a melody.

## Pattern 1: Ding alone
Strike the ding with your dominant thumb. Let it ring completely to silence.
Wait 3 breaths. Repeat 8 times.

## Pattern 2: Ding + one field
Strike the ding. While it rings, gently add one tone field.
Start with the A3 field (a perfect fifth). Then try Bb3 (minor 6th) — hear the tension.
Then D4 (an octave) — hear the resolution.

## Pattern 3: Field circle
Walk slowly around the field circle: A3 → Bb3 → C4 → D4 → E4 → F4 → G4 → A4 → A3.
No rhythm — just tone by tone, one breath per strike.

## Pattern 4: Ding as pulse
Use the ding as a slow heartbeat (one stroke every 2 seconds).
Above it, improvise freely on the tone fields between ding strokes.

**Duration:** 10–15 minutes. This prepares the hands, ears, and attention for playing.

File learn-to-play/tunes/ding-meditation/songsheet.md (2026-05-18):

# Ding Meditation — Songsheet

**Tempo:** Free  **Meter:** Free  **Difficulty:** ★☆☆

## Session structure (15 minutes)
| Minutes | Activity |
|---|---|
| 0–3 | Ding alone: 8 strokes, listening to full decay |
| 3–6 | Ding + one field: explore all 8 fields with ding sustain |
| 6–9 | Field circle walk: one note per breath, ascending |
| 9–12 | Ding as pulse: improvise freely over slow ding heartbeat |
| 12–15 | Ding alone: 8 strokes again, listen for differences |

The handpan rewards unhurried attention. These patterns are the foundation of all advanced playing.

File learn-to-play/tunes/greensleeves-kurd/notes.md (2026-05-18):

# Notes: Greensleeves (D Kurd Adaptation)

**Provenance:** Traditional English ballad, documented from 1580. PD.
This adaptation substitutes Bb for B natural to fit the D Kurd scale. The melody remains
recognizable; the modal shift creates a slightly more melancholic quality.

**Range check:** A3–C5. The C5 (c') is the highest note — confirm your A4 field (field 8)
is reachable without crossing over other fields.

**Practice tips:**
1. The 3/4 feel should be a gentle, swaying waltz — not a march.
2. Practice the verse and chorus as separate units.
3. The dotted rhythms (F3/2 G/) = dotted quarter + eighth. Count 1-and-2, not 1-2-3.

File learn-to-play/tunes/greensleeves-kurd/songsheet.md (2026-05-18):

# Greensleeves (D Kurd) — Songsheet

**Key:** D natural minor  **Tempo:** ♩= 72  **Meter:** 3/4  **Difficulty:** ★★☆
**Range:** A3–C5  **Source:** Traditional English, 16th century, PD; adapted for D Kurd

## Music
```
X:3 T:Greensleeves (D Kurd) M:3/4 L:1/4 Q:1/4=72 K:Dmin
D | F3/2 G/ F D | C3/2 A,/ C E | D2 B, | A,3 |
C3/2 D/ C A, | B,3/2 G,/ B, D | C A, B, | A,3 |
F3/2 G/ F D | C3/2 A,/ C E | D G F | E3 |
E D C | B, A, B, | c A G | A3 D |
```

## Adaptation note
Traditional Greensleeves is in D dorian (B natural). This D Kurd adaptation uses
Bb3 instead of B natural — which fits your handpan's field layout perfectly.
The Bb gives the melody a slightly darker, more Aeolian quality.

## Handpan fingering
- Use right hand for melody fields; left thumb periodically returns to ding for bass
- The low A3 (A,) and D3 ding alternate as bass anchors
- The Bb3 (B,) field is the characteristic "Kurd color" — place it cleanly

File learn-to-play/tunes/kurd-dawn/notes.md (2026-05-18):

# Notes: Kurd Dawn

**Composition:** Original tune for handpan in D Kurd. MIT licensed — Heifer Zephyr.
Written to use the full field circle of the D Kurd scale, from A3 ding up to D5 (if available)
or A4 on the standard 8-field configuration.

**Range check:** A3–D5. If your handpan only has 8 fields (up to A4), the D5 (d' in ABC)
can be replaced with A4 (an octave lower) — it changes the peak slightly but maintains the shape.

**Practice tips:**
1. Begin session with the warm-up before this tune.
2. The half notes (4 eighth-notes = 2 beats) are your breathing space — don't rush them.
3. This is an advanced tune because of the cross-field navigation and sustained tone control.
4. Try recording yourself and listening back — handpan resonance blends beautifully on recording.

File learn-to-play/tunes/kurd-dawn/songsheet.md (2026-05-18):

# Kurd Dawn — Songsheet

**Key:** D Kurd (D natural minor)  **Tempo:** ♩= 80  **Meter:** 4/4  **Difficulty:** ★★★
**Range:** A3–D5  **License:** MIT (original — Heifer Zephyr)

## Music
```
X:4 T:Kurd Dawn M:4/4 L:1/8 Q:1/4=80 K:Dmin
D4 A,4 | D4 F4 | A4 G4 | F8 |
A4 c4 | d4 c4 | A4 G4 | E8 |
G4 F4 | E4 D4 | A,4 c4 | D8 |
F4 A4 | c4 d4 | A4 F4 | D8 |
```

## Character
Four phrases of gradual emergence and resolution. The piece opens with the ding (D3) and rises
to D5 at the emotional peak of phrase 2, then gradually returns to the D foundation.
Each half note and whole note should ring completely — this is music for space, not fill.

## Handpan technique notes
- Opening: right-hand fingertip on D4 field, left thumb on ding (D3) simultaneously.
- Phrase 2 peak: the d4 (D5) may require reaching to the upper register of the field circle.
- Long notes: resist the urge to add extra strikes — silence is part of the composition.
- End: final D8 (whole note) = let the ding ring completely into silence.

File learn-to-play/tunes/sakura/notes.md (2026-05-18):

# Notes: Sakura Sakura (Handpan)

**Provenance:** Traditional Japanese koto melody, Edo period. PD worldwide.
The famous "In" scale (A Bb D E) is a subset of your D Kurd scale — 4 of 8 fields.

**Range check:** A3–E4. Uses only fields 1 (A3), 2 (Bb3), 4 (D4), 5 (E4).

**Practice tips:**
1. Start by learning which field is A3, Bb3, D4, and E4 by touch alone.
2. The A3→Bb3 half-step is the signature tension of this melody — feel it.
3. The final A4 (whole note) can be played on the A4 field (upper octave) for a brighter ending.

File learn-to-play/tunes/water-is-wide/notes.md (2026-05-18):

# Notes: The Water Is Wide (Handpan)

**Provenance:** Traditional English/Scottish ballad, PD. This arrangement sits in D natural minor
to match the D Kurd scale. The key (originally often G or F major) has been transposed to D.

**Range check:** A3–G4. All notes are on the 8 standard tone fields of D Kurd.

**Practice tips:**
1. The melody requires navigating from the low A3 and D4 fields up to G4 — map these positions first.
2. The dotted quarter + eighth figures (D3/2 F/) should flow lyrically, not mechanically.
3. This is the most expressive tune in the set — play it with feeling and slight tempo flexibility.

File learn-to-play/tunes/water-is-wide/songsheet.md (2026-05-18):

# The Water Is Wide — Songsheet (Handpan D Kurd)

**Key:** D natural minor  **Tempo:** ♩= 76  **Meter:** 4/4  **Difficulty:** ★★★
**Range:** A3–G4  **Source:** Traditional English/Scottish, PD

## Music
```
X:5 T:The Water Is Wide (D Kurd) M:4/4 L:1/4 Q:1/4=76 K:Dmin
D | D3/2 F/ D A, | C3 A, | A, B, C D | F4 |
F3/2 F/ F D | F G F D | C3/2 D/ C A, | D4 |
(repeat for each verse)
```

## Handpan notes
- The ding (D3 = D,) provides the bass anchor for the first note of each phrase.
- The pickup D (bar 1) is played on the D4 field, not the ding — establish the melody key first.
- The G4 field is the highest note in this arrangement — it appears only in bars 9–10.
- The tied final A,3/2 B,/ fades gently — touch the field lightly for the final eighth note.

**Provenance:** Traditional ballad, PD. Arranged for D Kurd handpan — freshly written.

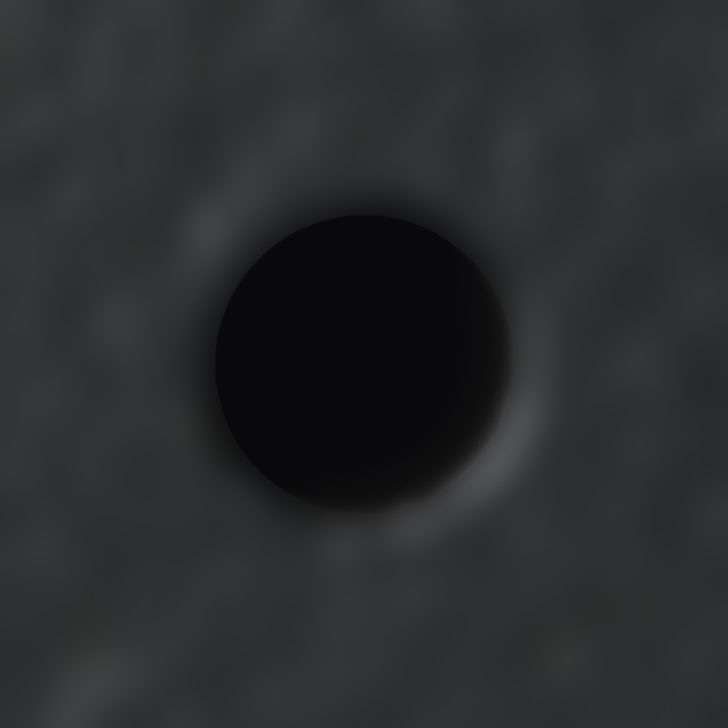
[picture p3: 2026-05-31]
images/macro/gu-port.png

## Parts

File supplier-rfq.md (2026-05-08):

# Supplier RFQ - Handpan Root-Mode Prototype

Hello,

I am preparing a first controlled D Kurd handpan prototype and need quote/support information for thin formed steel shells and related processing. This is a musical instrument tuning project, so dimensional consistency, material traceability, and low distortion matter more than lowest cost.

## Requested Quote

Please quote:

- One matched pair of handpan shells, nominal 21 in / 53 cm diameter.
- Sheet thickness: 1.0 mm preferred; please state actual tolerance.
- Material options: DC04 low-carbon steel suitable for nitriding, or 430/301 stainless if that is your standard handpan shell material.
- Top shell: uncut, suitable for Ding plus eight tone fields.
- Bottom shell: either uncut or with a centered 3.5 in Gu port; please specify port edge finish options.
- Rim condition: trimmed and matchable for adhesive closure.
- Any available nitriding, heat-treatment, or stabilization process details.

## Information Requested

Please include:

- Unit price and any volume breaks for 1, 2, and 5 shell pairs.
- Lead time and shipping estimate to the United States.
- Material certificate or material description.
- Thickness tolerance and typical thickness variation after forming.
- Expected diameter, height, rim flange, and roundness tolerances.
- Whether shells are supplied raw, nitrided, stainless, or otherwise treated.
- Known compatibility with handpan tuning and common adhesives.
- Photos or drawing/spec sheet for the shell geometry.
- Recommended handling, storage, and corrosion protection.

Substitutions are acceptable if you explain the material/process difference and any expected tuning impact. Please also note any distortion risk from heat treatment after forming.

Thank you.

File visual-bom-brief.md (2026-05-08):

# Visual BOM Brief

## Objective

Produce a visual BOM plate for the handpan prototype that shows the shell pair, Gu port, tuning frame, templates, dimple tooling, hammer set, measurement kit, adhesive, protective finish, and case. The plate should communicate what a builder must gather before beginning, while labeling quote-sensitive parts clearly.

## Layout

- Header: `D Kurd Handpan Root-Mode Prototype - Visual BOM`.
- Top row: assembled silhouette or shell pair reference image.
- Main grid: part number, part name, quantity, required spec, source status, estimated cost, and risk note.
- Side strip: measurement/tuning tools, because these are not optional for this project.
- Footer: `Prices and suppliers unverified; confirm current availability before purchase. Tone-field dimensions are layout estimates, not final tuning prescriptions.`

## Image Guidance

Use real supplier photos or shop photos where available. If concept renders are generated, label them as visual placeholders until replaced by actual parts. Avoid imagery that suggests final tone-field geometry is fixed by CAD.

## Critical Callouts

- Pre-drawn shells are recommended for the first build.
- Practice shell or scrap coupon testing is mandatory.
- Tuning measurement kit is part of the build, not a nice-to-have.
- Adhesive and treatment choices require coupon tests and supplier review.

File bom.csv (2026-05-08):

part_no | item | category | qty | unit | required_spec | estimated_cost | source_status | notes
HP-001 | Matched top and bottom shells | metal shell | 1 | pair | 21 in / 53 cm handpan shells, 1.0 mm DC04 low-carbon steel or approved stainless, no cracks or oil-canning | 250 | quote required | Pre-drawn shells strongly preferred over first-time hand sinking
HP-002 | Gas nitriding or approved surface treatment | heat treatment | 1 | service | Process compatible with 1.0 mm low-carbon handpan shells; supplier to confirm temperature cycle and distortion risk | 120 | quote required | Skip only for stainless branch with separate validation
HP-003 | Tuning support ring / frame | fixture | 1 | each | Rigid circular support for 21 in shell, padded contact, stable under hammering | 75 | shop fabricate | Can be welded flat bar or CNC-cut plate/ring
HP-004 | Oval tone-field template set | template | 1 | set | Removable Ding plus 8 oval field templates from current design table; acrylic, hardboard, or printed film | 35 | shop fabricate | Template is a layout aid, not final acoustic geometry
HP-005 | Dimple press tooling | tooling | 1 | set | Ball form and receiver dies for field dimples plus Ding forming support | 60 | shop fabricate or purchase | Radius set must be tested on scrap shell
HP-006 | Tuning hammer set | tools | 1 | set | Small cross-peen, ball-peen, nylon/rubber mallet, polished faces | 80 | purchase | Hammer faces must be smooth to avoid stress risers
HP-007 | Measurement kit | measurement | 1 | set | Chromatic strobe tuner, calibrated mic, audio interface or handheld recorder, FFT/spectrum software | 150 | purchase | Existing shop equipment can satisfy this row
HP-008 | Flexible shell adhesive | assembly | 1 | kit | High-strength flexible epoxy or handpan rim adhesive compatible with steel treatment and cure schedule | 45 | quote or test required | Do coupon test before final shell closure
HP-009 | Gu edge trim or ring | finish | 1 | each | 3.5 in ID edge trim, silicone/rubber ring, or rolled-safe finish | 15 | purchase | No sharp Gu edge after deburring
HP-010 | Surface protection and cleaning supplies | finish | 1 | set | Non-abrasive cloths, alcohol wipe, protective oil for nitrided shell or stainless-compatible cleaner | 30 | purchase | Confirm finish compatibility
HP-011 | Padded case | storage | 1 | each | 22 in handpan bag/case with dense padding | 120 | purchase | Protect tuned shell during settling and transport
HP-012 | Practice/scrap shell or coupon stock | training | 1 | set | Low-cost steel practice shell or scrap formed areas for hammer/treatment trials | 100 | purchase or shop scrap | Mandatory before committing final shell

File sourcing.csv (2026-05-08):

item | required_spec | search_terms | candidate_sources | unit_price_estimate | date_checked | lead_time_estimate | substitutes | source_risk
Matched handpan shells | 21 in / 53 cm, 1.0 mm DC04 or stainless, matched pair, clean forming, no cracks | 53cm handpan shells 1.0mm DC04 pair; handpan shell blanks; nitrided handpan shells | Ayasa-style handpan shell suppliers; Shellopan-style shell suppliers; local metal forming shop | 150-350 unverified | not checked | quote required | 430/301 stainless shells with separate validation | Supplier geometry and metallurgy dominate tuning repeatability
Gas nitriding service | Low-carbon steel shell nitriding compatible with thin formed musical shells | gas nitriding thin steel shell musical instrument; low carbon steel nitriding service | Local heat-treatment/nitriding shops | 50-200 unverified | not checked | quote required | Stainless shell path; controlled oxidation only after review | Distortion or embrittlement can ruin shell
Tuning frame material | Rigid ring for 21 in shell with padded support | 1/4 inch steel ring CNC cut; welded flat bar circle fixture | Local fab shop; shop-built fixture | 50-125 unverified | not checked | shop schedule | MDF mockup for layout only | Frame compliance can contaminate tuning measurements
Acrylic/hardboard templates | Ding and 8 oval tone-field templates from CSV dimensions | laser cut acrylic oval template handpan | Shop laser/CNC; local sign shop | 20-60 unverified | not checked | shop schedule | Printed acetate template | Template geometry is only starting layout
Tuning hammers | Polished small hammers, 4-8 oz range, varied faces | handpan tuning hammer set; jeweler cross peen hammer polished | Specialty handpan tool vendors; jeweler tool suppliers | 40-120 unverified | not checked | stock varies | Modify standard jeweler hammers | Poor hammer finish causes dents and stress risers
Measurement software/hardware | Strobe tuner plus FFT/spectrogram capture, calibrated mic preferred | Peterson strobe tuner; FFT audio tuner; calibrated measurement microphone | Existing shop kit; music suppliers | 0-250 unverified | not checked | stock varies | Phone tuner for rough work only | Uncalibrated setup can hide partial errors
Flexible shell adhesive | Steel-compatible flexible high-strength adhesive; documented cure and temperature range | 3M DP420 steel epoxy; flexible epoxy metal shell adhesive | Industrial adhesive suppliers | 20-75 unverified | not checked | stock varies | Handpan-specific rim adhesive after testing | Rigid or incompatible adhesive may crack or detune rim
Protective oil/finish | Compatible with nitrided or stainless handpan finish | handpan protective oil nitrided steel; stainless handpan cleaner | Music accessory suppliers | 10-35 unverified | not checked | stock varies | Mineral oil only after compatibility check | Wrong finish can stain or change surface feel
Padded case | 22 in handpan case with dense padding | 22 inch handpan bag hard case | Instrument case suppliers | 60-180 unverified | not checked | stock varies | Temporary padded storage crate | Transport damage can invalidate tuning work

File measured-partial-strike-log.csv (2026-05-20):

log_id | stage | shell_id | material_process | strike_field | neighbor_field | strike_location | hammer_or_mallet | mic_distance_cm | input_gain_db | room_noise_db | fundamental_target_hz | measured_fundamental_hz | fundamental_cents_error | octave_target_hz | measured_octave_hz | octave_cents_error | compound_fifth_target_hz | measured_compound_fifth_hz | compound_fifth_cents_error | struck_peak_db | neighbor_peak_db | crosstalk_delta_db | sustain_t60_s | audio_file | fft_image | status | notes
HPAN-STRIKE-001 | rough_tuning | TBD | TBD | Ding | nearest_field | TBD | TBD | TBD | TBD | TBD | 146.83 | TBD | TBD | 293.66 | TBD | TBD | 440.00 | TBD | TBD | TBD | TBD | TBD | TBD | TBD | TBD | measurement_required | Template row only; record real FFT/strobe capture before claiming Ding partial tuning.
HPAN-STRIKE-002 | rough_tuning | TBD | TBD | Field 1 A3 | adjacent_fields | TBD | TBD | TBD | TBD | TBD | 220.00 | TBD | TBD | 440.00 | TBD | TBD | 660.00 | TBD | TBD | TBD | TBD | TBD | TBD | TBD | TBD | measurement_required | Template row only; record cross-talk response into both neighbors.
HPAN-STRIKE-003 | rough_tuning | TBD | TBD | Field 2 Bb3 | adjacent_fields | TBD | TBD | TBD | TBD | TBD | 233.08 | TBD | TBD | 466.16 | TBD | TBD | 699.23 | TBD | TBD | TBD | TBD | TBD | TBD | TBD | TBD | measurement_required | Template row only; record cross-talk response into both neighbors.
HPAN-STRIKE-004 | rough_tuning | TBD | TBD | Field 3 C4 | adjacent_fields | TBD | TBD | TBD | TBD | TBD | 261.63 | TBD | TBD | 523.25 | TBD | TBD | 784.88 | TBD | TBD | TBD | TBD | TBD | TBD | TBD | TBD | measurement_required | Template row only; record cross-talk response into both neighbors.
HPAN-STRIKE-005 | rough_tuning | TBD | TBD | Field 4 D4 | adjacent_fields | TBD | TBD | TBD | TBD | TBD | 293.66 | TBD | TBD | 587.33 | TBD | TBD | 880.00 | TBD | TBD | TBD | TBD | TBD | TBD | TBD | TBD | measurement_required | Template row only; record cross-talk response into both neighbors.
HPAN-STRIKE-006 | rough_tuning | TBD | TBD | Field 5 E4 | adjacent_fields | TBD | TBD | TBD | TBD | TBD | 329.63 | TBD | TBD | 659.26 | TBD | TBD | 988.88 | TBD | TBD | TBD | TBD | TBD | TBD | TBD | TBD | measurement_required | Template row only; record cross-talk response into both neighbors.
HPAN-STRIKE-007 | rough_tuning | TBD | TBD | Field 6 F4 | adjacent_fields | TBD | TBD | TBD | TBD | TBD | 349.23 | TBD | TBD | 698.46 | TBD | TBD | 1047.69 | TBD | TBD | TBD | TBD | TBD | TBD | TBD | TBD | measurement_required | Template row only; record cross-talk response into both neighbors.
HPAN-STRIKE-008 | rough_tuning | TBD | TBD | Field 7 G4 | adjacent_fields | TBD | TBD | TBD | TBD | TBD | 392.00 | TBD | TBD | 784.00 | TBD | TBD | 1176.00 | TBD | TBD | TBD | TBD | TBD | TBD | TBD | TBD | measurement_required | Template row only; record cross-talk response into both neighbors.
HPAN-STRIKE-009 | rough_tuning | TBD | TBD | Field 8 A4 | adjacent_fields | TBD | TBD | TBD | TBD | TBD | 440.00 | TBD | TBD | 880.00 | TBD | TBD | 1320.00 | TBD | TBD | TBD | TBD | TBD | TBD | TBD | TBD | measurement_required | Template row only; record cross-talk response into both neighbors.
HPAN-CROSSTALK-MATRIX-001 | post_rough_tuning | TBD | TBD | all_fields | all_neighbors | fixed_center_strike | TBD | TBD | TBD | TBD | varies_by_field | TBD | TBD | varies_by_field | TBD | TBD | varies_by_field | TBD | TBD | TBD | TBD | TBD | TBD | TBD | TBD | measurement_required | Duplicate this row for every struck-field/neighbor-field pair after rough tuning and after final settle.

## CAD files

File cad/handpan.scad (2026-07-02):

// Handpan (D Kurd root-mode) — shell ENVELOPE ONLY
// SPDX-License-Identifier: CC-BY-4.0
//
// Source of truth: handpan-design-table.xlsx (sheet "Handpan") and
// ../design.md "Starting Inputs From Workbook" / cad/handpan-cad-brief.md.
// Values below are workbook-input scale dimensions, NOT measured/calibrated
// tuned geometry.
//
// Authority: pending_measurement. NOT fabrication authority until reviewed
// against a measured shell (see ../visual-output-register.csv,
// cad/mcp-session-log.md).
//
// EXPLICITLY OUT OF SCOPE (per cad/handpan-cad-brief.md "Do not model tuned
// tone fields as final manufacturable pitch geometry" — hand-refined,
// tuning-sensitive regions this envelope does not model):
//   - tone-field dimple geometry, depth, or profile (9 fields incl. Ding)
//   - tuned dimple layout / final pitch geometry
//   - hammered curvature, residual stress, or work-hardening effects
// This file models only the two-shell envelope (top shell, bottom shell,
// rim joint plane, Ding zone as a flat surface marker, Gu port) so a builder
// can block out shop space, fixtures, and template layout before tuned
// dimple work happens on a real shell.

// ---- Parameters (workbook inputs — see design.md Starting Inputs) ----
shell_diameter_in   = 21;    // workbook input: shell outside diameter (cad/handpan-cad-brief.md, design.md)
shell_height_in     = 9.5;   // workbook input: total shell height (design.md)
steel_thickness_mm  = 1.0;   // workbook input: steel thickness (design.md) — shown as shell wall, not tuned-field profile
gu_diameter_in      = 3.5;   // workbook input: Gu port diameter (design.md, cad/handpan-cad-brief.md)
gu_neck_depth_in    = 0.5;   // workbook input: Gu lip/neck depth (design.md "Gu lip / neck depth")
ding_zone_dia_in    = 5;     // assumption: Ding zone marker diameter for layout review only, NOT a tuned dimple spec (design.md Ding is "tuner-defined")

in = 25.4; // mm per inch
mm = 1;    // base unit for thickness param already in mm
steel_thickness_in = steel_thickness_mm / 25.4;

// ---- Modules ----

// Top shell: convex dome (bounding surface only, no tone-field dimples)
module top_shell() {
    difference() {
        sphere(d = shell_diameter_in * in, $fn = 96);
        translate([0, 0, -shell_diameter_in * in])
            cube([shell_diameter_in * in * 2, shell_diameter_in * in * 2, shell_diameter_in * in * 2], center = true);
        // inner shell (wall thickness cutaway, not a tuned profile)
        sphere(d = (shell_diameter_in - 2 * steel_thickness_in) * in, $fn = 96);
    }
}

// Bottom shell: concave dome with Gu port (bounding surface only)
module bottom_shell() {
    difference() {
        union() {
            difference() {
                sphere(d = shell_diameter_in * in, $fn = 96);
                translate([0, 0, shell_diameter_in * in])
                    cube([shell_diameter_in * in * 2, shell_diameter_in * in * 2, shell_diameter_in * in * 2], center = true);
                sphere(d = (shell_diameter_in - 2 * steel_thickness_in) * in, $fn = 96);
            }
        }
        // Gu port bore through the pole of the bottom shell
        translate([0, 0, -shell_diameter_in * in / 2])
            cylinder(h = shell_diameter_in * in, d = gu_diameter_in * in, center = false, $fn = 48);
    }
}

// Ding zone: flat marker disc at the top-shell pole for layout reference only
// (NOT a tuned dimple — design.md: "formed convex dome, tuner-defined")
module ding_zone_marker() {
    translate([0, 0, shell_diameter_in * in / 2 - 1])
        cylinder(h = 1, d = ding_zone_dia_in * in, center = false, $fn = 48);
}

// ---- Top-level assembly (approximate rim-joined shell pair) ----
module handpan_shell_envelope() {
    rim_gap_in = shell_height_in - shell_diameter_in; // negative = shells overlap at rim per height budget; layout aid only
    color("SlateGray") top_shell();
    color("DimGray") translate([0, 0, rim_gap_in * in])
        mirror([0, 0, 1])
        bottom_shell();
    color("Gold") ding_zone_marker();
}

handpan_shell_envelope();

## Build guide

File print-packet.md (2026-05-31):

# Handpan Print Packet

## Cover

Project: D Kurd Handpan Root-Mode Prototype
Status: Private research build packet
Source workbook: `handpan-design-table.xlsx`
Primary warning: final handpan tuning is empirical and tuner-led.

## Build Intent

This packet gives the shop enough structure to procure shells, build fixtures, lay out the scale, document forming, tune iteratively, validate measured behavior, and review whether the prototype is ready for broader sharing.

## Root Specifications

| Parameter | Value |
|---|---:|
| Scale | D Kurd |
| Notes | D3, A3, Bb3, C4, D4, E4, F4, G4, A4 |
| Shell diameter | 21 in |
| Shell height | 9.5 in |
| Steel thickness | 1.0 mm |
| Gu port | 3.5 in nominal |
| Material path | nitrided DC04 preferred |

## Shop Sequence

1. Inspect shell pair and document material/geometry.
2. Cut/deburr/finish Gu if not supplied.
3. Build tuning support ring and layout templates.
4. Rough-form Ding and tone fields.
5. Tune top shell in measured passes.
6. Rest and drift-check before shell closure.
7. Bond shells only after coupon and dry-fit tests.
8. Final tune through Gu, rest, retune, and validate.

## Validation Summary

Use `validation.csv` as the control sheet. Required evidence includes cents error for all fundamentals, octave and compound-fifth partial behavior, sustain, cross-talk, Gu response, and post-rest drift.

## Release Gate

Keep private until the measured build log and safety/process choices have been reviewed by a human handpan tuner and metal-forming lead.

## Included Files

- `design.md`
- `bom.csv`
- `sourcing.csv`
- `cut-list.csv`
- `validation.csv`
- `validation-loop.csv`
- `assembly-manual.md`
- `supplier-rfq.md`
- `drawing-brief.md`
- `visual-bom-brief.md`
- `visual-output-register.csv`
- `handpan-starter.wl`
- `risks.md`
- `photo-shotlist.md`
- `capstone-deck.md`
- `capstone-manifest.json`

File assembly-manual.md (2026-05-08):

# Handpan Assembly Manual

## Build Status

This manual is for a first D Kurd handpan prototype. It assumes purchased or professionally formed shells. First-time hand sinking is treated as a separate training project because shell geometry and thickness consistency are central to tuning repeatability.

## Tools And Setup

- Stable tuning stand or support ring.
- Smooth-faced tuning hammers, rubber or nylon mallet, and dimple tooling.
- Calipers, micrometer, flexible tape, radius gauges, and layout templates.
- Calibrated microphone or consistent recording setup, strobe tuner, and FFT/spectrogram software.
- Deburring tools, non-marring clamps, adhesive applicator, PPE, hearing protection, eye protection, gloves, and ventilation.

## Phase 1 - Incoming Inspection

1. Photograph both shells from top, side, inside, rim, and Gu area.
2. Record shell diameter, height, rim roundness, mass, and thickness map.
3. Inspect for cracks, wrinkles, hard creases, oil-canning, corrosion, and sharp rim defects.
4. Reject or branch the packet if shell thickness, material, or geometry differs materially from the design assumptions.

## Phase 2 - Gu Port

1. If the bottom shell is not pre-cut, mark the Gu center from the shell datum.
2. Cut a 3.5 in nominal port only with the shell supported.
3. Deburr both sides fully.
4. Roll, trim, or protect the port edge so it cannot cut the player.
5. Measure actual diameter and lip depth; enter these into the workbook and Wolfram model.

## Phase 3 - Layout

1. Establish a centerline and clock reference on the top shell.
2. Mark the Ding center and eight surrounding tone fields using removable templates.
3. Use the workbook clock positions as layout references, then adjust for real shell curvature and hand clearance.
4. Mark each field name, note, target fundamental, octave, and compound fifth on low-tack tape.

## Phase 4 - Rough Forming

1. Practice on scrap or a rejected shell before touching the real top shell.
2. Raise or form the Ding first, leaving final pitch margin.
3. Form each surrounding field dimple and shoulder gradually.
4. Avoid sharp dents, creases, or localized thinning.
5. Stop frequently to measure pitch tendencies and visible deformation.

## Phase 5 - Top Shell Tuning

1. Tune Ding D3 first.
2. Tune surrounding fields from low to high: A3, Bb3, C4, D4, E4, F4, G4, A4.
3. For every field, measure fundamental, octave, and compound fifth.
4. After adjusting any field, remeasure all previously tuned fields.
5. Keep a tuning log with hammer location, hammer type, strike force estimate, measured cents change, and comments.
6. Do not chase final cents before the shell has rested; rough stability matters first.

## Phase 6 - Rest And Drift Check

1. Let the tuned top shell rest for at least 24 hours.
2. Remeasure every field and partial under the same microphone setup.
3. If any field drifts more than 15 cents, continue top-shell tuning before assembly.
4. Repeat until the top shell is stable enough to justify closure.

## Phase 7 - Shell Closure

1. Dry-fit the shells and mark rim alignment.
2. Confirm Gu access allows final tuning reach.
3. Perform adhesive coupon testing before final closure.
4. Apply a continuous, controlled bead of approved flexible adhesive.
5. Clamp evenly without distorting the rim.
6. Cure according to adhesive data sheet and shop temperature.

## Phase 8 - Final Tuning

1. After cure, remeasure all 27 partial targets.
2. Tune through the Gu using small increments.
3. Record cross-talk matrix and sustain data.
4. Let the assembled pan rest one to two weeks.
5. Repeat remeasure and retune cycles until drift meets the acceptance target.

## Phase 9 - Finish And Storage

1. Remove residue without abrasive damage.
2. Protect nitrided steel with compatible oil, or clean stainless according to supplier guidance.
3. Install safe Gu edge trim if used.
4. Store in a padded case away from temperature shock and impacts.

## Stop Conditions

Stop and review with a human tuner or metal-forming lead if the shell cracks, buckles, rings with persistent buzzes, shows uncontrolled drift, develops sharp creases, or cannot hold the 1:2:3 partial relationship after multiple measured passes.

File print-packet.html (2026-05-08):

# D Kurd Handpan Root-Mode Prototype

Private research build packet | Source: handpan-design-table.xlsx

Final tuning is empirical. Formulas in this packet are first-order sanity checks, not final pitch predictions.

## Root Specifications

Parameter | Value
Scale | D Kurd
Notes | D3, A3, Bb3, C4, D4, E4, F4, G4, A4
Shell | 21 in diameter, 9.5 in height, 1.0 mm steel
Gu | 3.5 in nominal port with measured final lip/edge
Material path | Nitrided DC04 preferred; stainless is a separate measured branch

## Build Sequence

1. Inspect shells and record material, thickness map, mass, diameter, height, and rim condition.
2. Prepare Gu edge and verify safe finish.
3. Build tuning support ring and removable layout templates.
4. Rough-form Ding and tone fields on a supported shell.
5. Tune fundamentals, octaves, and compound fifths with FFT evidence.
6. Rest, remeasure, and retune before shell closure.
7. Bond shells after coupon testing and dry fit.
8. Final tune through Gu; repeat one-week rest and retune cycles.

## Release Gate

Keep private until a human handpan tuner and metal-forming reviewer approve the measured prototype data and process assumptions.

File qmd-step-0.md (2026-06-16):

# QMD Step 0 Record

Date: 2026-05-29.

Commands run before packet edits:

```sh
qmd search "handpan" -c instrument-builds
timeout 25 qmd query "handpan tuning packet"
```

Usable keyword hits:

- `instrument-builds/docs/handoffs/2026-05-08-github-sprint-round-2/dan-round-2-handpan.md`
- `instrument-builds/docs/handoffs/2026-05-08-github-sprint/dan-handpan-and-cajon.md`
- `instrument-builds/skills/v4/instrument-maker-v4/references/solidworks-templates/handpan.md`

Relevant retrieved guidance:

- Prior handpan lanes said the repo was useful but not close-ready without
  measured shell data, specialist tuning review, and clear public-readiness
  gates.
- The handpan design-table reference says template values are placeholders,
  not validated shop dimensions, and that measured pitch/tuning corrections
  belong in validation or sidecar tables.

Semantic query result:

- `qmd query "handpan tuning packet"` crashed inside Bun after the timeout
  reported `timeout: the monitored command dumped core`.

No QMD result supplied measured partials, cross-talk values, CAD geometry, or
tuning corrections for this issue #7 patch.

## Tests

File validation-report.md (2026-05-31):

# Validation Report

**Status:** validator-clean root packet plus Round 31 V5 issue surfaces; physical prototype validation has not started; not measured, build-ready, or public-ready.

## Automated Checks

| Check | Result |
|---|---|
| v4 installed validator | Pass, 0 findings |
| repo-local v4 root validator | Pass, root layout, 0 findings |
| Required packet files | Present |
| CAD/CNC/drawing handoff | Present, with starter SVG drawings |
| Visual authority register | Present, `visual-output-register.csv` |
| Empirical validation loop | Present, `validation-loop.csv` |
| MCP provenance note | Present, `cad/mcp-session-log.md`; no MCP artifacts generated |
| Public release posture | Not public-ready; see `public-release-checklist.md` |

Commands run:

```bash
python3 /home/tony/.codex/skills/instrument-maker-v4/scripts/validate_packet.py /mnt/c/Users/Tony/Documents/GitHub/handpan --json
python3 /mnt/c/Users/Tony/Documents/GitHub/instrument-maker/skills/v4/instrument-maker-v4/scripts/validate_packet.py /mnt/c/Users/Tony/Documents/GitHub/handpan --json --mode auto
```

## Clean Checks

- `design.md` states the coupled-plate plus Helmholtz model and labels it as first-order only.
- `bom.csv`, `sourcing.csv`, and `cut-list.csv` keep supplier, quote, and template assumptions explicit.
- `assembly-manual.md` uses a purchased/professionally formed shell path for the first controlled prototype.
- `validation.csv` separates predicted targets from unmeasured prototype results.
- `validation-loop.csv` makes shell inspection, material/process evidence, forming, heat treatment, partial tuning, cross-talk, Gu response, and human review explicit measurement gates.
- `measured-partial-strike-log.csv` is present as a Round 35a evidence landing zone for strike/FFT/cross-talk rows; it contains template rows only and does not record measured tuning evidence yet.
- `visual-output-register.csv` marks starter SVG/PDF/explorer visuals as concept-only and limits authority to workbook/design-table planning inputs.
- `risks.md` covers metal forming, heat/work-hardening, tuning repeatability, acoustic model risk, manufacturing limits, and public-release review.
- `handpan-starter.wl` provides a sweep surface and cents-error helpers without claiming calibrated field geometry.
- `cad/handpan-cad-brief.md` and `cnc/fixture-cnc-brief.md` limit CAD/CNC to inspection, templates, and fixtures.
- `drawings/01-top-layout.svg` and `drawings/02-gu-section-fixture.svg` provide starter review drawings and label tone fields as tuner-adjusted.
- `public-release-checklist.md` separates private packet completion from public release.

## Release Gates

| Gate | Current state | Required before public release |
|---|---|---|
| Packet completeness | Validator-clean | Keep clean after future edits |
| Specialist review | Not done | Experienced handpan maker reviews layout, shell process, and tuning workflow |
| Supplier/process evidence | Not done | Shell material, process history, and any heat/surface treatment documented |
| Measured tuning data | Not done | Populate `measured-partial-strike-log.csv` and `validation.csv` with fundamentals, partials, cross-talk, sustain, Gu response, and drift |
| Drawing maturity | Starter review drawings only | Add actual-shell drawing updates and measurement overlay |
| Public claims review | Not done | Confirm wording does not imply a proven finished-instrument recipe |

## Escalated To Human Review

| Gate | Why it remains open | Human action |
|---|---|---|
| Handpan tuning method | Final field contours, hammer sequence, and partial balancing depend on expert tuning practice. | Review with a handpan tuner before treating the packet as a build recipe. |
| Material process | DC04 nitriding, stainless, and any heat treatment path change stiffness and residual stress. | Obtain supplier process data and keep branches separate in measurement logs. |
| Measured acoustics | No real shell has been measured for cents error, partials, cross-talk, sustain, Gu frequency, or drift. | Populate `validation.csv` after a controlled prototype build. |
| Public release | Supplier/IP/process details and handpan maker history need care. | Keep private until safety, supplier, tuner, and IP/public-release review are complete. |

## Current Verdict

The packet is materially useful as a private research/prototype handoff. It is not public-close-ready until measured shell data, specialist tuner review, supplier/process evidence, and public-claims review exist.

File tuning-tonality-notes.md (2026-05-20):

# Handpan Tuning And Tonality Notes

## Acoustic Reference Basis

These notes cite the local instrument-maker-v4 references used for this L2
packet:

- `references/new-instruments-v4.md` section `Handpan`: the governing model is
  coupled membrane/plate plus Helmholtz; the plate formula and Gu formula are
  coarse sanity checks, not final tuning predictors.
- `references/acoustic-models.md` section `Membranes And Plates`: handpan and
  steel-pan tone fields are shaped/tuned zones with multiple partials; document
  target partials, field geometry, steel thickness, forming method, and
  post-form tuning process.

## 9-Note Scale Of The Pan

Round 3 L2 target: D Kurd, a common handpan tonality with a D3 Ding and eight
surrounding fields:

| Field | Note | MIDI | Fundamental Hz | Octave target | Compound fifth target | Tonality role |
| --- | --- | ---: | ---: | ---: | ---: | --- |
| Ding | D3 | 50 | 146.83 | 293.66 | 440.00 | Root / tonal center |
| 1 | A3 | 57 | 220.00 | 440.00 | 660.00 | Fifth below upper field set |
| 2 | Bb3 | 58 | 233.08 | 466.16 | 699.23 | Modal color / minor sixth color |
| 3 | C4 | 60 | 261.63 | 523.25 | 784.88 | Flat seventh / open modal color |
| 4 | D4 | 62 | 293.66 | 587.33 | 880.00 | Octave root |
| 5 | E4 | 64 | 329.63 | 659.26 | 988.88 | Ninth / melodic lift |
| 6 | F4 | 65 | 349.23 | 698.46 | 1047.69 | Minor third color |
| 7 | G4 | 67 | 392.00 | 784.00 | 1176.00 | Fourth / suspended color |
| 8 | A4 | 69 | 440.00 | 880.00 | 1320.00 | Upper fifth |

The musical target is a D-centered minor/modal pan with strong root-fifth
anchors and enough adjacent stepwise motion for simple melodies. It should be
reviewed as a tonal program, not as proof that field dimensions are final.

## Partial And Tonality Acceptance

For each field, log:

- Fundamental cents error.
- Octave partial cents error near 2x.
- Compound fifth partial cents error near 3x where measurable.
- Sustain and decay character.
- Cross-talk into neighboring fields.
- Tonal role notes: root, fifth, color tone, or melodic connector.

Use `measured-partial-strike-log.csv` as the evidence landing zone. Each row
must name the shell, material/process path, struck field, neighbor field,
recording setup, measured partial peaks, cross-talk delta, sustain, and the
audio/FFT artifact used. Until those rows contain real shell captures, the
table above is a target map only, not a tuning result.

## Gu / Body Coupling Note

The workbook Gu estimate near 115 Hz is a Helmholtz sanity check. Measure the
actual Gu response only after the shells are joined because shell volume, port
lip, adhesive/rim geometry, and internal damping affect the result.

## L2 Boundary

This note supports tuner review and prototype planning. L3 requires measured
field data from a real handpan shell plus specialist review of shell process,
hammer sequence, and final claims.

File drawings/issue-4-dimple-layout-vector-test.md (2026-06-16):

# Issue #4 Dimple Layout Vector Test Brief

Status: **pending_measurement**. This is an honest V5 scaffold for the
Illustrator-MCP dimple-layout vector test requested by issue #4. It is not a
vector drawing, not CAD, not DXF, and not tuned dimple geometry.

## Purpose

Define the packet surface a future Illustrator-MCP session must fill in when
real measurement and review data are available. The goal is to keep the future
vector test traceable without inventing coordinates in this no-MCP lane.

## Authority Register Row

The active V5 register row is `ISSUE4-ILL-001` in
[`../visual-output-register.csv`](../visual-output-register.csv).

Current authority:

- `authority`: `pending_measurement`
- `dimension_claim`: `pending_measurement`
- `fabrication_required`: `true`, because a future dimple-layout vector could
  be mistaken for a template if promoted without review.
- Current artifact: this brief only.
- Future possible output: an Illustrator-authored or Illustrator-reviewed vector
  layout after measurement and tuner review. No future file path is reserved as
  fabrication authority by this lane.

## Inputs Required Before MCP Work

Do not run or promote an Illustrator vector test until the packet has:

- measured top-shell outside diameter, usable crown/profile notes, and thickness
  map;
- measured or reviewed Ding center, field clocking, and available field
  envelope clearances;
- tuner or forming-lead review of field order, strike zones, dimple shoulder
  clearance, and neighbor isolation;
- explicit decision on whether the vector is a removable film/template,
  inspection overlay, print plate, or fabrication template;
- updated `validation-loop.csv` evidence for issue #4 gates.

## Non-Claims

This lane did not:

- open Illustrator MCP or any other MCP tool;
- generate SVG, DXF, AI, PDF, CAD, or coordinate geometry;
- infer dimple centers, oval dimensions, or shoulder curves from the starter
  SVG;
- calculate tuning frequencies or partials;
- promote the existing top-layout SVG beyond `concept_only`.

## Future Session Log Contract

When an actual Illustrator-MCP session happens, append a real row to
[`../cad/mcp-session-log.md`](../cad/mcp-session-log.md) with:

- real session id or timestamp;
- measured/reviewed input authority ids;
- output file paths;
- role set to `dimple_layout_vector_test` or narrower;
- authority result kept at `pending_measurement` until measured and reviewed;
- notes naming any manual edits and any rejected geometry.

## Promotion Gate

Issue #4 remains blocked at `pending_measurement` until a future change commits
the actual vector output, records its MCP provenance, validates it against
measured shell data, and has human tuner/forming review. Until then, this brief
is a planning surface only.

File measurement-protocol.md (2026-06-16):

# Handpan Measurement Protocol

Status: V5 issue #7 scaffold. This protocol defines the measurement surface
only. No partials, cross-talk values, tuning frequencies, CAD geometry, or DXF
coordinates were measured or generated in this patch.

## Purpose

The handpan packet already names a D Kurd target program, but target notes are
not measured acoustics. Before the packet can claim tuned partials, field
isolation, sustain, or public-ready musical behavior, a real shell must be
measured with repeatable strike, microphone, and environment records.

This protocol controls two blank logs:

- `data/measured-partial-log.csv`
- `data/cross-talk-strike-log.csv`

## Required Capture Setup

Record these setup facts for every measurement session:

- shell identifier and build state;
- date/time and operator;
- room, background noise note, temperature, and relative humidity if available;
- microphone or tuner model, gain setting, and distance from the struck field;
- strike implement, strike zone, and strike force class;
- audio file or screenshot reference;
- reviewer and review status.

If any setup item is missing, keep the row status as `needs_recapture` or
`blocked`; do not promote it to measured evidence.

## Measured Partial Log

Use one row per field and partial role. Required partial roles:

- `fundamental`
- `octave`
- `compound_fifth`

The log intentionally separates target labels from measured data. Do not enter
a frequency, cents offset, or pass/fail result unless it came from a real
capture file or tuner/strobe reading.

Minimum pass toward L3/L4:

- Ding plus all eight surrounding fields have reviewed `fundamental` rows.
- Every surrounding field has reviewed `octave` and `compound_fifth` rows, or
  an explicit `not_resolved` status with tuner note.
- Each row links to an audio or screenshot artifact.
- A human tuner or measurement reviewer signs off the interpretation.

## Cross-Talk Strike Log

Use one row for each struck/listener pair that matters to field isolation. At
minimum, record all adjacent neighbors and any field that audibly responds.
For full matrix review, include the Ding and all eight surrounding fields as
both struck and listener positions, excluding same-field pairs.

Minimum pass toward L3/L4:

- Rough-tune matrix is recorded before shell closure or before final tuning.
- Final/settled matrix is recorded after shell closure and rest.
- Rows include the struck-field reference amplitude and listener response
  method, even when the numerical value is still pending.
- A tuner reviews any listener response that exceeds the project gate or is
  musically intentional.

## Claim Gate

Until both logs are populated from real evidence:

- say `target note`, `planned partial`, or `pending measurement`;
- do not say `measured partial`, `validated tuning`, `isolated field`, or
  `build-ready tuning recipe`;
- treat SVGs, design tables, and print packets as planning artifacts only;
- keep the packet at L2 V5 candidate status.

## Next Physical Work

1. Assign shell IDs and mark the shell state before tuning.
2. Capture baseline impulse responses before final hammer work.
3. Populate `data/measured-partial-log.csv` through rough tune, rest, and final
   tuning states.
4. Populate `data/cross-talk-strike-log.csv` at rough tune and final/settled
   states.
5. Update `validation-report.md` only after the logs contain real evidence.

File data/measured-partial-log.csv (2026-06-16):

session_id | shell_id | build_state | field_id | partial_role | target_label | measurement_status | measured_hz | cents_offset | amplitude_db | decay_note | strike_id | mic_position | audio_ref | screenshot_ref | environment | operator | reviewer | review_status | notes
TBD | TBD | pre_tune | Ding | fundamental | Ding target | measurement_required | TBD | TBD | TBD | TBD | TBD | TBD | TBD | TBD | TBD | TBD | TBD | unreviewed | Blank structure only; no measured value.
TBD | TBD | pre_tune | Ding | octave | Ding octave target | measurement_required | TBD | TBD | TBD | TBD | TBD | TBD | TBD | TBD | TBD | TBD | TBD | unreviewed | Blank structure only; no measured value.
TBD | TBD | pre_tune | Ding | compound_fifth | Ding compound-fifth target | measurement_required | TBD | TBD | TBD | TBD | TBD | TBD | TBD | TBD | TBD | TBD | TBD | unreviewed | Blank structure only; no measured value.
TBD | TBD | pre_tune | Field_1 | fundamental | field target | measurement_required | TBD | TBD | TBD | TBD | TBD | TBD | TBD | TBD | TBD | TBD | TBD | unreviewed | Duplicate this row for each field/state after capture.
TBD | TBD | pre_tune | Field_1 | octave | field octave target | measurement_required | TBD | TBD | TBD | TBD | TBD | TBD | TBD | TBD | TBD | TBD | TBD | unreviewed | Duplicate this row for each field/state after capture.
TBD | TBD | pre_tune | Field_1 | compound_fifth | field compound-fifth target | measurement_required | TBD | TBD | TBD | TBD | TBD | TBD | TBD | TBD | TBD | TBD | TBD | unreviewed | Duplicate this row for each field/state after capture.

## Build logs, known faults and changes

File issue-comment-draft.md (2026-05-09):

# Issue Comment Draft

Draft for `tonykoop/handpan#1` only. Do not post automatically.

Round 2 sprint update:

The local `handpan` repo is materially stronger, but I would not call it public-close-ready yet. The packet is now clearer about the boundary between useful private prototype documentation and claims that require a real handpan maker plus measured shell data.

- Round 1 starter drawings are present:
  - `drawings/01-top-layout.svg`
  - `drawings/02-gu-section-fixture.svg`
- Round 2 added `public-release-checklist.md` and wired it through README, validation, risks, drawing index, site, and validation rows
- `validation-report.md` now distinguishes validator-clean packet status from public-release readiness
- `risks.md` now calls out the specialist boundary: tone-field forming, partial balancing, and drift control are experienced handpan-maker work
- `validation.csv` now has explicit supplier/process and public-claims release gates
- CAD/CNC/drawing scope remains honest: fixtures, templates, support rings, inspection, and documentation, not final tone-field machining

Validation run:

```bash
git -C /mnt/c/Users/Tony/Documents/GitHub/handpan status --short
python3 /home/tony/.codex/skills/instrument-maker-v4/scripts/validate_packet.py /mnt/c/Users/Tony/Documents/GitHub/handpan --json
python3 /mnt/c/Users/Tony/Documents/GitHub/instrument-maker/skills/v4/instrument-maker-v4/scripts/validate_packet.py /mnt/c/Users/Tony/Documents/GitHub/handpan --json --mode auto
```

Both validators passed with 0 findings.

Remaining assumptions/blockers before any public release:

- no measured shell, Gu, cents-error, partial, cross-talk, sustain, or drift data yet
- no supplier-verified shell/material/nitriding/heat-treatment process window yet
- final field contours, hammer sequence, and partial balancing remain human-tuner work
- public release still needs specialist review, supplier/process evidence, measured build log, safety review, and public-claims review

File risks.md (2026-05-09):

# Risks

## Executive Summary

This packet should be treated as private research documentation until a human handpan tuner, metal-forming reviewer, and safety/IP reviewer have signed off. The design is buildable as a disciplined prototype packet, but it is not a guaranteed path to a finished instrument.

## Metal Forming Hazards

- Thin steel shells can crack, crease, buckle, or oil-can under forming and tuning impacts.
- Hammering creates flying chips, rebound hazards, high sound levels, and repetitive strain risk.
- Sharp Gu and rim edges can cut the builder or player if not fully deburred/protected.
- Torch or heat-treatment work creates burn, fire, fume, oxidation, and distortion hazards.
- Clamping a curved shell under stress can release suddenly or dent the shell.

Mitigation: PPE, hearing protection, smooth hammer faces, deburred edges, stable fixtures, scrap practice, fire-safe setup, and stop-work criteria for cracks or uncontrolled deformation.

## Heat And Work-Hardening Assumptions

- The packet assumes nitrided DC04 as a first controlled material path, but actual supplier shells may have different forming history, hardness, and residual stress.
- Nitriding or other heat treatment can change shell stiffness, surface hardness, corrosion behavior, and tuning stability.
- Work-hardening from hammering is not represented by the first-order plate equation.
- Heat applied after rough tuning can move pitch or relax stresses unpredictably.

Mitigation: request material/process data, perform coupon tests, record hardness/process information where possible, and never mix stainless and nitrided assumptions in one measurement set.

## Tuning Repeatability

- Tone fields are dominated by hand-shaped curvature, dimple geometry, local stress, and coupling to neighboring fields.
- The same nominal oval dimensions can produce different pitches on different shells.
- Tuning one field can detune fields already completed.
- Shell closure, adhesive cure, settling time, and transport can move pitch.
- The 1:2:3 partial relationship may not be reachable on a first shell without expert hammer technique.

Mitigation: tune iteratively, record every pass, measure all prior fields after each change, and plan multiple settle/retune cycles.

## Acoustic Model Risk

- Plate and Helmholtz equations are sanity checks only.
- The shell is a coupled curved structure, not an isolated flat plate.
- Gu predictions depend on actual volume, port shape, edge treatment, and assembled-shell leakage.
- FEM without measured material/stress calibration can look authoritative while being wrong.

Mitigation: label formulas as first-order, use measured cents error as the authority, and back-fit models only after prototype data exists.

## Manufacturing Limits

- First-time hand sinking is unlikely to produce consistent shells for a musical prototype.
- Purchased shells may still vary enough to require packet updates.
- CNC can make fixtures and templates, but cannot cut final pitch into a handpan field.
- Adhesive choice and rim compression can alter shell response.

Mitigation: buy or professionally form shells for the first prototype, keep CNC scope to fixtures/templates, and run adhesive coupons before closure.

## IP And Public Release Review

- The handpan family has a sensitive maker history, brand/trade-name distinctions, and technique knowledge that may not be appropriate to publish as a definitive recipe.
- Supplier photos, proprietary shell dimensions, tuner methods, and heat-treatment details may be copyrighted, confidential, or trade-secret-like.
- Public claims that the packet teaches finished handpan tuning could mislead builders.

Mitigation: keep the repo private until reviewed, avoid brand confusion, cite sources sparingly, use original measurements, and publish only as a research/build-log packet with clear uncertainty labels.

## Specialist Boundary

- Tone-field forming, partial balancing, and drift control are specialist handpan-maker work.
- CAD, CNC, SVG drawings, and workbook estimates in this repo are allowed to define fixtures, templates, measurement points, and documentation, but not final tuned field geometry.
- If an experienced tuner changes the field order, hammer approach, material path, Gu detail, or acceptance targets, the packet should be revised before any public release.

Mitigation: route the packet through `public-release-checklist.md`, preserve the tuning log, and treat specialist feedback as design data rather than commentary.

## Difference Between This Packet And A Guaranteed Instrument

This packet provides: procurement specs, layout geometry, first-order physics, build order, validation gates, drawing briefs, and documentation scaffolding.

It does not provide: a proven hammer recipe, final tone-field contours, supplier-verified process windows, calibrated FEM, measured prototype corrections, or assurance that the first build will be musically acceptable.

## Red-Team Verdict

Proceed only as a controlled prototype. Keep private until human review, measured tuning evidence, supplier/process evidence, and public-claims review exist.

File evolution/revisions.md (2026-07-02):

# Revision Register — handpan

| Rev | Date | Parent | Delta | Downstream artifacts invalidated |
| --- | --- | --- | --- | --- |
| A | 2026-07-01 | — | Stage 0 intake of current masters (cad/handpan.scad shell envelope + handpan-design-table.xlsx + handpan-starter.wl). | none (no alpha/beta/production artifacts exist yet) |

Stage 0 only. Gate A has not been run; no Alpha compiles, vendor quotes, or production lock exist for this product. Tone-field/dimple tuning geometry remains measurement-required and out of scope for the CAD master.

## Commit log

2026-05-02 Initial scaffold: Handpan
    [handpan-design-table.xlsx]
2026-05-18 feat(learn-to-play): add handpan starter songbook (#3)
    * feat(learn-to-play): add handpan starter songbook (R4 claude-dan)
    Drop learn-to-play/ with 00-INDEX.md, scales/, fingerings/, and
    5 tunes (ABC + LilyPond + songsheet + notes). All tunes are
    public-domain traditional arrangements or original Heifer Zephyr
    compositions (MIT). Notation is at concert pitch; no external
    rendering tools required to read the ABC files.
    * fix: strip trailing whitespace in learn-to-play songsheets
    ---------
2026-05-18 Add Round 31 handpan V5 issue gates (#6)
    [validation-loop.csv, visual-output-register.csv]
2026-05-20 Add handpan strike evidence log scaffold (#8)
    [measured-partial-strike-log.csv, validation-loop.csv, validation.csv]
2026-05-30 Add #7 strike-log completeness gates and #4 dimple-layout register rows (#10)
    validation.csv: add VAL-023 (partial-log completeness pre-gate),
    VAL-024 (cross-talk matrix completeness pre-gate), VAL-025 (dimple
    layout fabrication pre-gate) — protocol structure only, no measured
    values invented (Refs #7).
    visual-output-register.csv: pre-register SVG-003 and DXF-001 for the
    planned Illustrator MCP dimple-layout artifacts, authority=pending;
    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
    [validation.csv, visual-output-register.csv]
2026-05-31 Add image-gen concept prompt; wire explorer images
    Canonical docs/image-gen-prompt.md (Hero/In-Context/Detail/Negative + concept-only
    guard) and explorer.html <img> wiring for the agy render pipeline.
2026-05-31 Add image-gen concept prompt; wire explorer images
2026-06-16 v5(handpan): merge unique R2 measurement/validation work (#14)
    * v5(handpan): honest packet surface (Refs #7)
    * v5(handpan): honest packet surface (Refs #4)
    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
    [cross-talk-strike-log.csv, measured-partial-log.csv, validation-loop.csv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]
2026-06-21 Wire 4 rendered concept image(s) into explorer gallery
2026-07-02 V5 packet refresh: status line, provenance, parametric OpenSCAD master, evolution intake
    Branch feat/7-shell-tuner-decision was already merged into origin/main via
    PR #15 (decision-log.md, capstone-manifest.json update); normalized to main
    before this pass. Status line was already approved (kept, with
    measurement-required caveat). Authored cad/handpan.scad as a
    non-dimensional shell envelope only (top/bottom shell, rim joint, Ding-zone
    marker, Gu port) from workbook-input scale dimensions; tone-field dimple
    geometry explicitly out of scope per cad/handpan-cad-brief.md. Validator:
    0 failures, 7 warnings (pending_measurement WARN expected per V5
    standard) — same 0 failures as baseline (6 war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
    [handpan.scad, visual-output-register.csv]
